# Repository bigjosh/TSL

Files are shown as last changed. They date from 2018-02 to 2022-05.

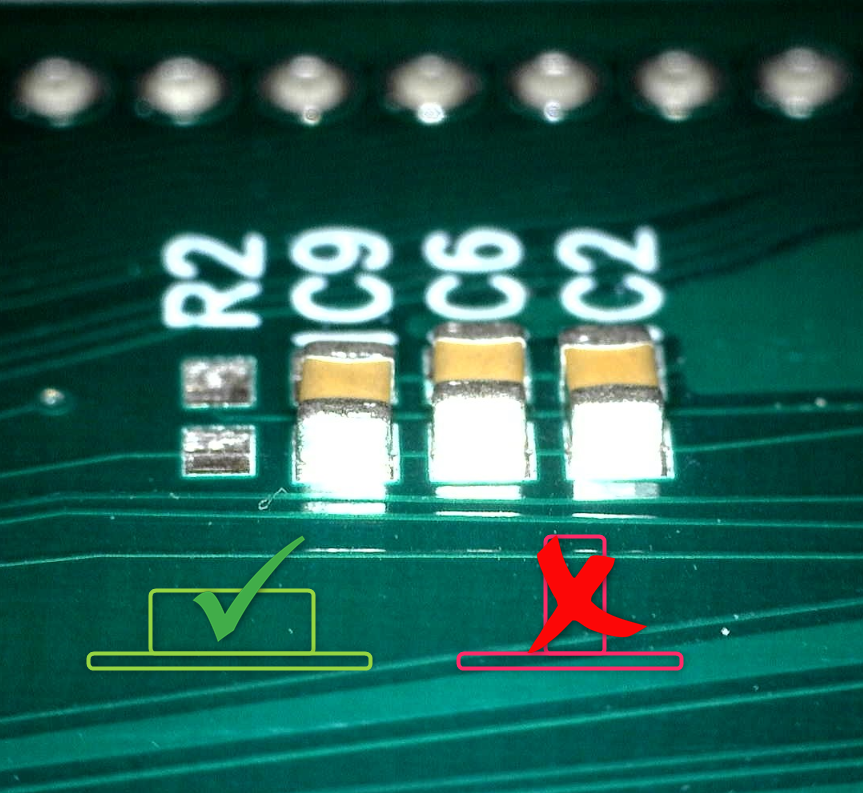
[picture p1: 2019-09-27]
hardware/orientation photos/orientation C2-C6-C9.png

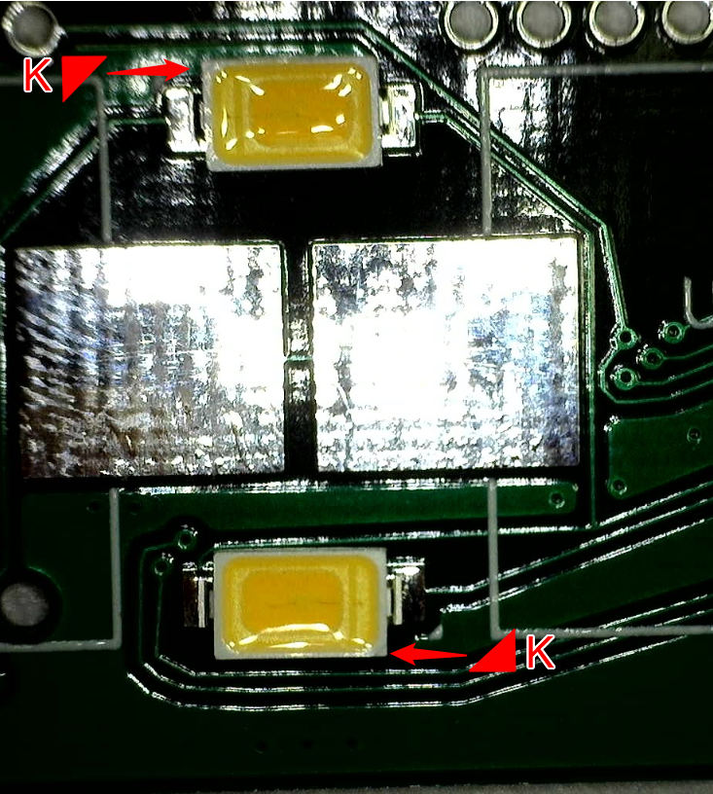
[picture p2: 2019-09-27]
hardware/orientation photos/orientation L1-L2.png

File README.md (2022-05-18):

# TSL



PCB and firmware for the CW&T Time Since Launch project.

Buy one here...
https://shop.cooperhewitt.org/products/time-since-launch

Or here...
https://www.uncommongoods.com/product/time-since-launch-clock

## Design goals:

* Run for decades on 2xAA batteries.
* Stay accurate to to within ±2ppm over the lifetime.  
* Replaceable batteries, with continued timekeeping during a reasonable battery swap time period.  

## Critical parts:

* ATXMEGA128B3 processor for LCD driving and supervision. 
* RX8900 RTC for precision timekeeping
* 2x  AIExpress 6-digit, 7-segment dynamic LCD glass 
* 2x Energizer Ultimate Lithium AA batteries
* Optional 32768Hz tuning fork quartz watch crystal 

## XMEGA EEPROM usage

We use a block at the start of EEPROM to ...

1. Initially set the current real time on first power up at the factory.
2. Remember that we set the current time at the factory. 
3. Remember if/when the trigger was pulled.
4. Remember if the RTC has ever lost power. 
 
Here is the format of that block...

    #define EEPROM_ADDRESS_STARTIME     EEPROM_ADDRESS( 0)  // Set by the at the Factory to real time GMT when initially programmed. RX8900 register block layout. Values are BCD.
    #define EEPROM_ADDRESS_STARTFLAG    EEPROM_ADDRESS( 8)  // Set 0x00 to indicate that STARTTIME block has time in it, set to 0x01 when STARTTIME set to the RTC the first time we power up

    #define EEPROM_ADDRESS_TRIGGERTIME  EEPROM_ADDRESS(10)  // Set to RTC time when the trigger pin is pulled. RX8900 register block layout. Values are BCD.
    #define EEPROM_ADDRESS_TRIGGERFLAG  EEPROM_ADDRESS(18)  // Set to 0x01 when the trigger pin is pulled and the RTC time is aves to the TRIGGER_TIME block.

	#define EEPROM_ADDRESS_LOWVOLTFLAG  EEPROM_ADDRESS(20)  // Set to 0x01 if we ever power up and find a low voltage condition.

The times are in RX8900 register block format....

| Address | Function |
| - | - |
| 00 |  SEC | 
|01  | MIN | 
|02  | HOUR |
|03  | WEEK |
|04  | DAY |
|05  | MONTH | 
|06  | YEAR |
|07  | RAM |

We ignore the `WEEK` register, but set it to a sensical value (1-7) since the datasheet warns of problems otherwise. 

We use the `RAM` location to hold our century interlock. 

### Century interlock

The RX8900 only saves 2 digits for the year, so when we roll from 2099 to 2100, the year will go from 99 to 0.
This would make us loose 100 years worth of days on the first battery change of the new century when we go to
compute how long since the pin was pulled.

To buy ourselves extra centuries, we use a century interlock stored in the RAM register of the RX8900.
When we first program a unit (presumably in the 1st half of the 2000 century), we set the interlock to '00' BCD (0x00).

On every power up (typically due to battery change) every 10 - 30 years(? We'll see!), we check the current year. If it is greater than 50 and the century interlock is even, then we increment the century interlock. If it is less than 50  and the century interlock is odd, then we increment the century interlock. This also has the effect of re-writing the EEPROM every few decades, which [may or may not extend the retention](https://electronics.stackexchange.com/questions/411616/for-maximum-eeprom-readability-into-the-future-is-it-better-to-write-once-and-le). 

When we want to compute the total days elapsed since epoch Jan 1, 2000 then we divide the century interlock by 2 and drop the remainder. We when multiply this by the number of days in an RX8900 century and we will get the correct value.

This will get us an additional 127 centuries of run time, which puts us at the year 14700. We will need to patch the firmware before then if we want to continue to keep accurate count.

### The leap year problem

The RX8900 counts any year ending in `00` as a leap year, but in real life 2100 is not a leap year.

This means that if a unit is programmed in the 2000's and triggered on 3/1/2100 then the trigger date in EEPROM will be 2/29/2100, and any day after that will be 1 day behind the actual calendar date when the trigger was pulled. The count will still always be right, and the only way you'd know about this is if you inspect the trigger time with the diagnostic mode or if you have to reset the RTC.

This divergence will increase by 1 for each non-leap year ending in `00` after 2000, including 2200 and 2300 (2400 is a leap). 

Why don't we just correct for this in the firmware? Well because as far as the RX8900 is concerned 2/29/2100 actually happened, so a trigger could happen on that day.

Since this problem is predicable we can account for it when resetting the RTC in units triggered after 2/28/2100. 

## Method of Operation

### Factory power up
The factory burns the firmware into flash and also stores the current GMT time into `STARTTIME` in the EEPROM block. 

On initial power up, firmware sees a new `STARTTIME` block in EEPROM and uses it to set the RTC. It then sets the `STARTFLAG` so that the time is not programmed again on subsequent power ups and executes a software reset to being normal operation with the new start time.  

If the trigger pin is out at start up we go into clock mode and show the current GMT time until the pin is inserted. THIS CLOCKMODE IS MEANT FOR TESTING ONLY. It is very high power (like 50x normal count!), so be sure to insert the pin as soon as you have verified the correct time. DO NOT USE A TSL IN CLOCKMODE AS A CLOCK. If you really want a TSL clock, we can make you power efficient firmware for that. 

Once the pin is in, we go into Ready To Launch mode. 
 
## Display modes

### Warm up mode

Every time the XMEGA powers up (on initial programming or after battery change), it will display a pretty sinewave pattern for 2 seconds while it waits for the RX8900 RTC to oscillator to stabilize. 

Do we need this? Well we certainly do not need it if the RTC is already running, but it is unclear if we can poll the RTC to see if it is running before the oscillator has settled. The datasheets are unclear. 
> 
> "Please perform initial setting only tSTA (oscillation start time), 
> when the built-in oscillation is stable."
> 

...so we wait. 

### Reset flags mode

For testing only - removed from production firmware.

Displayed for 2 seconds after each reset. Shows the reset flags currently set. We clear the flags after testing them, so there should only be one flag set indicating the reason for the most recent reset. 

Shows the word `rESEt` on the left LCD and the following possible flags on the right LCD...

| Letter | Name | Description |
| - | - | - |
| P | Power On | Initial power up |
| E | External | The RESET pin was pulled low<br>(We disable this pin)  |
| b | Brown out | Brown out voltage reached<br>(We disable the brown out detector) |
| d | Download | PDI download triggered reset |
| S | Software | Software generated reset<br>(We trigger this after setting the time) |
| U | Undefined | One of the two undefined flags were set |  

### Set Clock mode

Shows "SEt CLoC" on the LCD.  

Shown when we initially set the start time from EEPROM into the RTC during factory programming. 

After this we execute a software reset.  

### Clock mode

Shows current real time as MMDDYY HHMMSS with blinking ":"'s.

This time comes from the RTC and should be correct GMT ±2ppm if it was programmed correctly at the factory. 

This mode is shown at start up if we have a good start time, but no trigger time and the pin is not inserted. 

We existing this mode when the pin is inserted and goto Ready To Launch mode.     

WARING: Clock mode uses about 50x as much power as normal Time Since Launch mode, so don't leave it on for too long! For diagnostics only! 

### Ready To Launch mode 

Shows a mesmerizing winding pattern with 1Hz update rate. 

The purpose of this pattern is to show the user that we are ready and willing, and also make apparent any bad LCD segments stuck either on or off. 

We enter this mode on power up if the trigger pin has never been pulled before, and we exit it when the pin is pulled. When the pin is finally pulled, we blink the flashbulb LEDs and save the current time from the RTC into EPPROM in the `TRIGGERTIME` block to remember the trigger time and set the `TRIGGERFLAG`.  

### Time Since Launch Mode

Here we count up the days, hours, minutes, and seconds since the trigger was pulled. 

When we reach 1,000,000 days we switch to Long Now mode. 

### Where Has the Time Gone mode

Shows the time the trigger pin was pulled in MMDDYY HHMMSS blinking at 0.5Hz. 

Indicates that the trigger pin was pulled and we marked the moment shown on the display, but since then the real time was lost (RTC lost power) and needs to be set before we can show Time Since Launch mode. 

The unit can be factory serviced and set with the correct real time and it will pick up where it left off. 

### Clock Error mode

Shows `cLoc Error` blinking forever.

Indicates that the trigger pin has never been pulled, and that the real time was lost. The start time must be set again before we can go to Ready To Launch mode.    

This likely means that the unit was stored as old new stock for 100+ years and the batteries we allowed to go completely dead before first use. The unit can be factory serviced to set the real time and then will be ready for first trigger.   

### Low Battery mode

Blinks the little battery icons at 1Hz to indicate that a low battery voltage was detected.

The battery voltage is checked once at start power up and then every 8 days in Time Since Launch mode starting at the update from day 0 to day 1. If the voltage is less than about 2.6 volts, then we go into low battery mode.

When you see this, you should swap out the batteries for new ones. No need to run, you likely have moths to years to get it done before the time is lost. Be sure to use Energizer Ultra.  

Work quickly, you may have as little as 10 seconds of coast time if the battery voltage is very low. Be sure to have the new ones ready before you remove the old ones. Change the batteries one at a time - taking the first old one out and putting the new one in, then taking the second old one out and putting the new one in. This will minimize the amount of time that the unit is completely unpowered (even having low batteries installed will charge the RTC hold over capacitor). 

If after you change the batteries you still see low battery mode, then pull one of the batteries out and wait for the LCD to go blank and then quickly put the battery back in. 

Note that we intentionally do not check for low batteries during Ready to Launch mode. It is expected that a TSL will spend most of its decades in Time Since Launch mode, so no point in wasting good power right at the beginning of its long life. Also, what cut off would we use? Should it be higher than the cut off during Time Since Launch mode? If your TSL has been sitting around for more than 20 years and you are about to have a big moment and you want to play it safe, you can always prophylacticly put in new batteries. 

### Long Now mode

Shows `999999 235959` blinking forevermore. 

Indicates that the trigger was more than 1 million days (~2740 years) ago so we can not display it accurately. 

The idea here is to avoid problems of people trying to ebay old TSL units that have rolled over by misrepresenting their true age. 

### Bad Interrupt Mode

Shows "bAd Int" blinking forever.

This means that an unexpected interrupt happened. This would be very unexpected indeed.  

The only interrupts that are ever enabled are for the trigger pin and the 2Hz FOUT tick (risgin and falled edge of 1Hz) coming from the RTC, and we turn off the trigger pin after the pin is pulled.

### EEPROM Error Mode

Shows `EEPro ErrorX` blinking forever.

This is shown on start-up if the EEPROM is in an inconsistent state. This usually means either that the EEPROM was never programmed (it defaults to 0xff's), or it got corrupted somehow. 

The `X` after `EEPro` is a code that tells you the first problem found (they are checked in order). 

| Code | Reason 
| - | - |
| 1 | Invalid `LOW VOLTAGE FLAG` |
| 2 | Invalid `START FLAG` |
| 3 | Invalid `TRIGGER FLAG` |
| 4 | `TRIGGER FLAG` set but `START FLAG` not set |
| 5 | `TRIGGER TIME` is in the future | 
| 6 | _[elided]_ |
| 7 | Invalid `START TIME` | 
| 8 | Invalid `TRIGGER TIME` | 

#### Codes 1-3

All flags must have a value of either 0 (not set) or 1 (set).

#### Code 4

How could the user have pulled the trigger if we never set the start time? Impossible. 

#### Code 5

To find the Time Since Launch, we need to subtract the time now from the `TRIGGERTIME`, so the `TRIGGERTIME` must be *before* now. 

#### Code 6

[elided] 

#### Code 7 

`STARTTIME` failed validity checks on start up. (i.e. month was greater than 12)

#### Code 8 

`TRIGGERTIME` failed validity checks on start up. (i.e. month was greater than 12)

## `STARTTIME` delay offset

When programming the `STARTTIME` into the EEPROM, be sure to account for (1) the time it takes to generate the EEPROM file and program it into the unit, and (2) the 1 second warm up delay when the unit first comes up. 

## Diagnostics

### Factory program

On the initial power-up after the time as been set to the value supplied in the `STARTTIME` EEPROM block, the display will show the Clock mode for as long as the trigger pin is out. 

This is handy for verifying the correct time was programmed. 

### Field service 

There are two test pins on the 6-pin ISP connector on the board labeled `B` and `T`. They are internally pulled up, so you connect them the to the ground pin (labeled `G`) to activate them.

The reset pins are checked at start up and at the end of each hour. 

#### `B` Pin

Grounding the `B` pin will show a series of three display phases, switching once per second.

The sequence will repeat if pin `B` is still grounded after phase 3 is displayed.  

##### Phase 1

The LCD displays the `STARTTIME` block from EEPROM. 

Left `:` is on to differentiate this display. 

##### Phase 2

Will show the stored trigger time. The left & right `:`'s are lit to differentiate this display.

The display will show "no triG" if the EEPROM trigger flag is not set.   

The right `:` is lit to differentiate this display.

(Note this changed in ver 1.04)

##### Phase 3

The left LCD module shows `XXVOLt` where `XX` is the current Vcc voltage as read by the XMEGA analog to digital converter. There is an implied decimal point between the two digits, so `31VOLT` means the XMEGA just sampled the Vcc as 3.1 volts. Note that this voltage can be slightly lower than what it will be when running normally because this diagnostics screen uses much more current than the normal modes do.    

The right LCD module shows `VErXXX` where `XXX` is the current firmware version as defined in the TSL.c source code. There is an implied decimal point between the first and second digits so `VER101` indicates firmware version 1.01.    

#### `T` Pin

Grounding the `T` pin will show  current time as loaded from the RTC on the display. This will show even if the clock has not been initialized. 

Left decimal point means low voltage flag set in RX8900 right now.

Right decimal point means low voltage flag is set in EEPROM (we have seen a low voltage on RX8900 in the past). Once set, the low voltage flag in EEPROM stays set forever. 

The low voltage flag indicates that the voltage to the RTC dropped low enough that the RTC at least stopped counting, and possibly lost all the values in the time registers.

The RX8900 low voltage is checked and the EEPROM flag is set *after* this diagnostic screen, so you can see the RTC showing low voltage but the EEPROM flag not set if this is the first time we are powering up since the low voltage event happened on the RTC.  

The low voltage flag is cleared in the RX8900 when it is programmed with the start time at the factory. 

(Note this changed in ver 1.04)

## Interesting twists

We actually have two oscillators running simultaneously here.

The ATMEGA uses either the XTAL or the internal ULP oscillator to drive the LCD controller. The xtal uses about 0.3uA less current, but requires an extra part (the ULP is built in to the XMEGA).  

The RX8900 is programmed to generate a 1Hz output pulse (FOUT) that is connected to an IO pin on the XMEGA. The rising and falling edges of each of these pulses causes an interrupt on the XMEGA which wakes it from deep sleep. On waking, the XMEGA checks the FOUT pin to see if it has changed, and if not then it goes back to sleep. We do this to filter spurious interrupts that can be caused by noise from static electricity from rubbing the glass.  

On the falling FOUT edge the XMEGA then increments the count and updates the display and goes back to deep sleep until the next interrupt. 

The resistor on the FOUT line is to reduce the amount of current that flows from the RTC into the MCU during a battery change. This current can flow because there is an internal clamping diode inside the MCU that is forward biased if the pin voltage is higher than the Vcc voltage, which can happen during a battery change since the RTC is running off of the backup capacitors but there is no power to the MCU. We hope that RTC will stop driving FOUT when it sees FOE drop (FOE is connected to the MCU Vcc line). 

Diode D1 serves two purposes. Firstly, it prevents power from flowing from the backup capacitors into the MCU during a battery change. This will hopefully extend the time the user has to successfully complete the change since the RTC alone uses much less power than the MCU. Both sides of the diode also serve to protect both the MCU and RTC from reverse voltage in the case the batteries are inserted backwards.     

We also did a lot of work to save power on the display updates by basically writing an optimizing compiler that transforms a sequence of LCD steps (like `0000` to `5959`) into minimal cycle count AVR assembly language that will display those steps. Do read more about it in the [code2code.MD document](code2code.md).      

## Build notes

gcc optimization: `-O3 -flto`

```
-x c -funsigned-char -funsigned-bitfields -I"C:\Program Files (x86)\Atmel\Studio\7.0\Packs\atmel\XMEGAB_DFP\1.1.55\include"  -O3 -flto -ffunction-sections -fdata-sections -fpack-struct -fshort-enums -g2 -Wall -mmcu=atxmega128b3 -B "C:\Program Files (x86)\Atmel\Studio\7.0\Packs\atmel\XMEGAB_DFP\1.1.55\gcc\dev\atxmega128b3" -c -std=gnu99 -MD -MP -MF "$(@:%.o=%.d)" -MT"$(@:%.o=%.d)" -MT"$(@:%.o=%.o)" 
```

## Fuse programming notes

The only change we make to default fuses is to change `FuseByte4` to `0xEE`.

This sets the `RSTDISBL` fuse...

> Bit: 4 – RSTDISBL: External Reset Disable
> This fuse can be programmed to disable the external reset pin functionality. When this is done, pulling the r
> ill not cause an external reset. A reset is required before this bit will be read correctly after it is changed

We do this to avoid inadvertent resets. We have seen cases where the built-in pull-up on the reset line is not enough to resist a strong electric field generated by static electricity on the outside of the tube in dry winter conditions. 

## Unit factory programing

Check out the [programming readme](programming/readmne.MD) for more info. 

## Current Usage

| Mode | Vcc=3.55V| Vcc=2.6V |
| - | -: | -: |
| Ready to Launch | 5.5uA | 5.3uA | 
| Time Since Launch | 6.0uA | 5.4uA |
| Long Now | 4.7uA | 4.2uA | 
| Low Battery | 3.9uA |  3.5uA |
| quiescent | 3.9uA | 3.4uA |

Quiescent mode means that all LCD segments are turned off, interrupts are disabled, and the XMEGA is put into Power Save mode. The only current draw should be from the RX8900 and the XMEGA quiescent power.   

3.55V is approximately the voltage of a pair of fresh Energizer Ultra batteries.
2.6V is approximately the voltage when we drop to Low Battery mode.

Note that voltage drop over time is not expected to be linear with Energizer Ultra cells. These batteries are predicted to spend most of their lives towards the higher end of the voltage range and only start dropping when they get near to their end of life.  

### Color

Comparing Time Since Launch mode to Long Now mode lets us see how much power is used in the the timekeeping code.  

Comparing Low Battery mode to Long Now mode lets us see how much of the power is dependent on just how many LCD segments are lit.

Comparing maximum and minimum operating voltages for different modes lets us see how much of the power usage is dependent on supply voltage, and how that relates to time spent in sleep versus active mode (Time Since Launch spend a lot of time in active, whereas Long Now and Low Battery spend almost none).

Comparing Low Battery mode to quiescent mode lets us see how much power used by the interrupt ISRs (confounded slightly by those tiny little battery icon segments and the single blink instructions in Low Battery mode).    

### Conclusions

There is not much to be gained by elimination the ISR overhead. This is surprising. Those unnecessary PUSHes and POPs still bug the crap out of me. 

There are gains of up to 1uA possible from having fewer LCD segments lit. Not sure how actionable this is. We could, say, save 0.5uA by blinking the Time Since Launch mode screen off every other second. It is likely that Ready To Launch mode's low power relative to Time Since Launch mode is due to the fact that it has only 1 segment lit per digit. 

Probably the best place to focus effort is on the Time Since Launch update code since there is about 1uA on the table and the device spends the vast majority of its live here.  

### Measurement conditions

Production board from initial batch. Bare PCB on my desk (not in tube).  
68F
80%RH

(Higher humidity and temperature tends to increase current consumption. Need some different weather conditions to quantify this!) 

## Status

Firmware is Feature complete but could use more testing. 

We are at an average of <6uA running current over the full voltage range.

If the battery datasheets are to be believed, this suggests a runtime of ~66 years. Even derating a few percent for internal leakage, we should get a decent run time between battery changes. 

## Future directions

### Software 
Find a way to suppress the ISR call on interrupts. Maybe by playing with interrupt priorities? We do not use the ISR and just do an empty return, so why waste all those cycle on PUSHing and POPing. 

### Hardware

Trivially reroute J2:2 and J2:3 to avoid the unnecessary vias. I know one will ever see these because they are under the LCD and battery holder, but still they bug me.    

Add a supplemental pull-up resistor to ~RESET line. In dry conditions it is possible to reset the XMEGA over the built-in pull-up when it is in the tube using static fields. Don't really need this since the firmware is spurious RESET tolerant, but cleaner.

Try using the ~INT line from the RTC to trigger an update on the MCU. We would use an internal pullup on the MUC pin. Since this pin on the RTC is open collector, this would eliminate any power drain from the RTC to the MCU during battery changes. To be seen if this set up uses significantly more power during normal operation since the RTC is shorting the pull-up to ground. We could potentially turn off the pull-up very quickly after waking, and then wait to turn it back on until we know that the ~INT pin is open again. The ~INT pin is closed fort about 7ms and then automatically opened again, so we could probably use the Watchdog timer to sleep during this period.

Add an Ultra-Low Quiescent Current Low-Dropout Linear Regulator in front of the XMEGA. The current drops from 5.6uA@3.2V to 4.2uA@2.0V, so some potential for savings here, but worth the extra part?  

Try driving the LCD bias voltages directly from the battery voltage. The Energizer Ultra's have remarkably stable voltage over most of their lives and we go into Low Battery mode when they start to drop, so might be able to save power by disabling the XMEGA charge pump and finding contrast settings that work with the battery voltage direct?

If possible find a static LCD and bit bang the segments. Since our batteries have such a flat voltage curve, we could avoid the biasing circuits and charge pump and save a lot of power.  

If the datasheets are to be believed, switching to an ultra low power ARM (like SAM22L or STM32L) or STM8 could reduce power drastically, at the cost of higher cost. This needs to be tested.

It might be possible to do temperature compensation inside the MCU and get rid of the RX8900 while achieving more accuracy (would take a higher precision temp sensor than the one in the RX, and better characterization of each individual unit) . While this could also potentially save power in theory, it seems unlikely that it would in practice since that part astonishingly pulls less than 1uA in practice.

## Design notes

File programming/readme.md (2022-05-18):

# TSL Factory Programming

Each TSL needs to get programmed with firmware and the current time before it can launch!

This setup assumes you are programming using a Windows computer with Atmel Studio 7 installed and an Atmel MkII programmer.

TODO: This windows stuff is hokey and brittle. Use a dedicated Raspberry Pi with GPS to do programming.

## Set up

Get to a command prompt in the directory with this readme. 

Make sure your computer has the right time and date. It is probably a good idea to install an NTP client or GPS slave at some point to keep the time accurate to the second.

### Adjust `atprogram` path 

Find the location of you "atprogram.exe" that was installed with Atmel Studio. If it is not at `C:\Program Files (x86)\Atmel\Studio\7.0\atbackend\atprogram.exe` then edit the `burnthis.bat` file to fix the path.

### Adjust programming lag offset

Since all time calculations inside a running TSL are relative, it does not practically matter how accurate the programmed clock time is for normal operation. Having accurate TSL time is nice when a TSL needs to be reset. It is also nice to have it accurate to +/-1 second just so we can keep track of how how much TSLs are drifting in the wild over time.     

The programming procedure takes more than a second to complete, so if we just programmed the current time then the TSL would end up behind.

You can specify a number of seconds to add or subtract to the current time when programming the TSL to account for these delays in the programming process. 

First try programming a unit with the default offset and then compare the clock time on the TSL to the the time on the computer. If the TSL is off by more than +/- 1 second then adjust the value of `offset` in the `burnthis.bat` file and try again.

### Accurate time base

We want the local windows clock to be as accurate as possible since all the TSLs programmed will be based on this time (+/- the lag offset above). You can manually set the windows clock though Windows' settings, but probably best to install an NTP client on the programming computer to always keep it synced.

Here is one that is free and works...

http://www.timesynctool.com/

You can check against the real time here...

https://time.gov/

## Procedure

1. Connect the TSL to the programming jig.
2. Enter the command `burnthis.bat` on the command line followed by the unit serial number. (Use up arrow or F3 on subsequent passes)
3. Watch it program.
4. Remove the TSL and check that is has the correct GMT time on the LCD.
5. Insert the trigger pin.
6. Confirm that the TSL goes to Ready To Launch mode and all the segments look good.

### Batch programming mode

If you enter just `burnthis.bat` without specifying a serial number, then you will go into batch programming mode where You will be asked to enter a serial number and after the programming cycle successfully competes then it will ask for the next serial number. 

This works great if you have a bar code scanner to enter the serial numbers.   

## How it works

### tsl-make-block

First the batch file uses the `tsl-make-block` to create a binary file to be programmed into the TSL EEPROM. The program checks the clock on the local PC, converts the current time to GMT, and then adds in the delay offset. Then it writes out the EEPROM data block in the format that the TSL firmware expects to find when it runs. The block contains:

1. The current time GMT
2. A flag that tells the firmware to copy this time to the RX8900 RTC when it sees it
3. The trigger time and flag, which we set to "not triggered yet". 
4. A flag that remembers if the RTC in the TSL has ever reported that it lost power, which we initialize to `not set`.
 
### atprogram
The batch file uses the `atprogram` command to actually download the firmware flash image and the newly created EEPROM data block into the XMEGA on the TSL.  The `atprogram` is equivalent to `avrdude` but it written by Atmel and runs on Windows and uses the Atmel drivers. We used `atprogram`  because `avrdude` can have problems talking to an `MkII` when Atmel Studio is installed because of USB driver conflicts.  

#### Fuses

The `atrprogram` command sets the fuses like so...

JTAGUSERID = 0xFF
WDWP = <none selected>
WDP = <none selected>
BOOTRST = APPLICATION
TOSCSEL = XTAL
BODPD = DISABLED
RSTDISBL = [X]
SUT = 0MS
WDLOCK = [ ]
JTAGEN = [X]
BODACT = DISABLED
EESAVE = [X]
BODLVL = 1V6

FUSEBYTE0 = 0xFF (valid)
FUSEBYTE1 = 0xFF (valid)
FUSEBYTE2 = 0xFF (valid)
FUSEBYTE4 = 0xEE (valid)
FUSEBYTE5 = 0xF7 (valid)

### Airtable integration

The programming cycle automatically inserts a record into the [Units database](https://airtable.com/tblunHqmlHFKtvaZ1/viw4lIvKlyMFLtk5F) for each unit programmed. 

Before creating the record, it checks so make sure there is already a record for the current firmware hash in the [Firmwares database](https://airtable.com/tbl5LY3zBKoeetbQW/viwRVB4nIbvjLaZ3i). If not, then it will fail with an error. If this happens, you need to add a record for the new firmware version.

### Airtable API key 

In order to update the databases in Airtable.com, this batch file needs to know your Airtable API key. You can get it here...

https://airtable.com/account

Copy the value if one is there, hit generate if not.

The first time you run the procedure below, you will be prompted to enter the API key. The key you enter will be stored in the Windows registry for the local user on the local computer so you do not need to enter again.

If you ever want to remove the stored API key (you are selling the computer, or you need to enter a new value), you can run this command...

`REG delete HKCU\Environment /V burnthis_airtable_api_key`

...and the next time you run `burnthis.bat`you will be asked to enter a new key.

### Checking your work

You can use the `read-eeprom.bat` batch file to read and print the eeprom of an attached TSL. It uses the `tsl-read-block.exe` utility to decode and print the data, and you can also use this utility to work directly with eeprom bin files created by `atprogram.exe` or the `Device Programming` function under `Tools` in Atmel Studio.  

### Sample block file

The `party-like.bin` eeprom block will set the clock to just after midnight on Jan 1, 2000. You can use the Atmel Studio "Device programming tools" or AVRDude to load this file into EEPROM for testing.

It was created with this command line...
```
tsl-make-block.exe party-like.bin -s 20000101000000
```

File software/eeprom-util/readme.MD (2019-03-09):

These utilities let you create and print TSL eeprom binary images. 

While you can use them direct on files, you usually want to use the batch files in `/programming` to access them.

Note that if you change any of these programs, you should copy the new binary to `/programming/eeprom-utils/bin`.

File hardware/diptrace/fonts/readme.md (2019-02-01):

The text on the bottom of he board uses the `Space Mono` font included here.

It must be installed on the computer to be able to generate gerber files for this PCB.

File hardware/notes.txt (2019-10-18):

1.
No ultrasound cleaning - RTC clock part U3 is sensitive to vibration.

2.
LCD parts L1 and L2 are to be hand soldered. They mount with the LCD face on the FRONT side of the PCB. 

3.
LCD parts L1 and L2 are heat sensitive. Avoid overheating when soldering.

4.
Use the solder reflow profile for RTC clock part U3, available on page 42 here...
https://support.epson.biz/td/api/doc_check.php?dl=app_RX8804CE&lang=en
Following this profile is critical for the performance of this part. 
All other parts are tolerant of this profile.

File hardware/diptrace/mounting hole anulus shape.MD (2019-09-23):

How to make an anulus from...
https://www.diptrace.com/forum/viewtopic.php?f=2&t=10961

---
Maybe someone else knows of a simpler method, but I haven't figured one out yet. Until then, here is a very involved procedure for getting the pad you need...

Phase I - Option A: Using DipTrace drawing tools
1) In the PCB Layout editor, clear the design area of all objects and make sure Units is set to mm.
2) Using the 2D drawing tools, create the desired shapes (in this case, two circles) in the Top Assy layer centered about the origin (0,0).
3) Go to the Main Menu and click on File, then Export and then DXF...
4) In the Export DXF dialog window, select the Top Assy layer, set Units to mm and enable the option [x]Use Design Origin.
5) Click on the [Export] button and save as a file named sketch to a convenient location (e.g. Desktop).

Phase I - Option B: Using a separate 2D Cad drawing program
1) Create the desired shapes (in this case, two circles) centered about the origin (0,0) using millimeters as your units.
2) Save as a *.DXF file named sketch to a convenient location (e.g. Desktop).

Phase II
1) In the PCB Layout editor, clear the design area of all objects and make sure Units is set to mm.
2) Go to the Main Menu and click on File, then Import and then DXF...
3) Select the newly-created file named sketch.dxf.
4) In the Import DXF dialog window, set DXF Units: Millimeters, Import Mode: Add, Convert Blocks: None, Convert to: Top, enable options [x]Fill closed areas and [x]Embedded Polygons.
5) Click on the [Import] button.
6) Go to the Main Menu and click on File, then Export and then DXF...
7) In the Export DXF dialog window, select the Top layer, set Units to mm and enable the option [x]Use Design Origin.
8) Click on the [Export] button and save as a file named pad to a convenient location (e.g. Desktop).

Phase III
1) In the Pattern Editor, create a new pattern name and clear the design area of all objects. Make sure Units is set to mm.
2) Go to the Main Menu and click on Pattern and then Import from DXF...
3) Choose the newly-created file named pad.dxf.
4) In the Import DXF dialog window, set DXF Units: Millimeters, Import Mode: Add, Convert to: Top Pads, enable options [x]Fill Closed Areas and [x]Embedded Polygons.
5) Click on the [Import] button.

Note: Due to how this special pad was created, you will not be able to resize it. Also, copying this special pad will result in the copies having the same pad number. You will have to manually renumber those additional pads.

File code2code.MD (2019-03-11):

# LCD update code that writes code

To save power, we want to spend as much time sleeping as possible. When we wake up, we need to update the LCD display as quickly as possible and then go back to sleep.

To this end, we want to find the optimal set of instructions to update the LCD display from the current value to the next one in as few cycles as possible. We need an LCD compiler!

The LCD display segments are represented as bits in the XMEGA LCD registers. Because the LCD module is multiplexed, these bits are not contiguous across registers. The bits for the segments in each digit are spread across as many as 4 registers (one for each of the common pins). 

Luckily the registers ended up organized so that each group of 4 registers controls a contiguous block of four digits. Here is a map of which registers hold segments for each of the 12 digits...  

### LCD register usage by digit map

| Reg  | 11 | 10 | 09 | 08 | 07 | 06 | 05 | 04 | 03 | 02 | 01 | 00 |
| ---  | -- | -- | -- | -- | -- | -- | -- | -- | -- | -- | -- | -- |
| [00] |  X |  X |  X |  X | | | | | | | | |
| [01] | | | | |  X |  X |  X |  X | | | | |
| [02] | | | | | | | | |  X |  X |  X |  X |
| [03] | | | | | | | | | | | | |
| [04] |  X |  X |  X |  X | | | | | | | | |
| [05] | | | | |  X |  X |  X |  X | | | | |
| [06] | | | | | | | | |  X |  X |  X |  X |
| [07] | | | | | | | | | | | | |
| [08] |  X |  X |  X |  X | | | | | | | | |
| [09] | | | | |  X |  X |  X |  X | | | | |
| [10] | | | | | | | | |  X |  X |  X |  X |
| [11] | | | | | | | | | | | | |
| [12] |  X |  X |  X |  X | | | | | | | | |
| [13] | | | | |  X |  X |  X |  X | | | | |
| [14] | | | | | | | | |  X |  X |  X |  X |
| [15] | | | | | | | | | | | | |
| [16] | | | | | | | | | | | | |

Notice how digits 00-03 all use the same set of registers (02, 06, 10, and 14)?

This means that as long as we know the full current value for the first 4 digits, we can blindly write to these registers without having to load them, adjust the bits, and rewrite them.

With all this in mind, we now know that we can represent an hour of updates (0000-5959 in the rightmost 4 digits) with a sequence of blind writes to registers 02 ,06, 10, and 14! 

This is a total of 3600 updates to these registers, but the updates are not just increments or bit shifts because the bits represent the 7 physical visible segments on the LCDs. For example, to show a `0` we have to light 6 segments, but to show a `1` we only have to light 2 segments. See?

So we have to map the LCD font into the bits of the registers. The fastest way to do this is to precompute the needed values for each of the 4 registers for each of the 3600 steps. 

We could store all of these precomputed values in an array in flash and then load them in a loop, but loading data  from flash costs cycles as does the overhead of loops. Since we have plenty of flash memory available, we instead will just explicitly hardcode each step into the sequence of instructions. The pseudocode looks like...

    1. Update register 02 with value that reflects LCD display of 0000.
    2. Update register 06 with value that reflects LCD display of 0000.
    3. Update register 10 with value that reflects LCD display of 0000.
    4. Update register 14 with value that reflects LCD display of 0000.
    5. Sleep until next update
    6. Update register 02 with value that reflects LCD display of 0001.
    7. Update register 06 with value that reflects LCD display of 0001.
    8. Update register 10 with value that reflects LCD display of 0001.
    9. Update register 14 with value that reflects LCD display of 0001.
    10. Sleep until next update
    11. Update register 02 with value that reflects LCD display of 0002.
    12. Update register 06 with value that reflects LCD display of 0002.
    13. Update register 10 with value that reflects LCD display of 0002.
    14. Update register 14 with value that reflects LCD display of 0002.
    15. Sleep until next update
    etc...
    
At first you might say "Why not only update the single register for the digit that changed?" But remember that the bits for each digit are scattered across the 4 registers. 
  
Here is a map of how that happens to land....
         
## Segment map of each digit 

        D
    C       E
        G
    B       F
        A

(NOTE: LCD modules are mounted upside down for maximum contrast when viewed from 30 deg above)
    
## Map of segments to (register:bit)

| Digit | A | B | C | D | E | F |
| - | - | - | - | - | - | - |
| 11 |  00:0 | 04:0 | 08:0 | 12:1 | 08:1 | 00:1 | 04:1 |
| 10 |  00:2 | 04:2 | 08:2 | 12:3 | 08:3 | 00:3 | 04:3 |
| 09 |  00:4 | 04:4 | 08:4 | 12:5 | 08:5 | 00:5 | 04:5 |
| 08 |  00:6 | 04:6 | 08:6 | 12:7 | 08:7 | 00:7 | 04:7 |
| 07 |  01:0 | 05:0 | 09:0 | 13:1 | 09:1 | 01:1 | 05:1 |
| 06 |  01:2 | 05:2 | 09:2 | 13:3 | 09:3 | 01:3 | 05:3 |
| 05 |  01:4 | 05:4 | 09:4 | 13:5 | 09:5 | 01:5 | 05:5 |
| 04 |  01:6 | 05:6 | 09:6 | 13:7 | 09:7 | 01:7 | 05:7 |
| 03 |  02:0 | 06:0 | 10:0 | 14:1 | 10:1 | 02:1 | 06:1 |
| 02 |  02:2 | 06:2 | 10:2 | 14:3 | 10:3 | 02:3 | 06:3 |
| 01 |  02:4 | 06:4 | 10:4 | 14:5 | 10:5 | 02:5 | 06:5 |
| 00 |  02:6 | 06:6 | 10:6 | 14:7 | 10:7 | 02:7 | 06:7 |

## Skipping redundant updates

We can, however, skip updating a register if it happens that none of the bits in that register changed between steps. This happens quite frequently, but it is not obvious when it will happen unless you memorize which segments map to which registers. It is just luck when the next digit happens to not change any segments in a given register. Here is a map of the changes to segments when the digit is incremented...   

## LCD changes by digit (`X`=changed)

| Digit |  COM0 | COM1 | COM2 | COM3 |
| - | - | - | - | - |
 | 00 | X | X | X | X |
 | 01 | X | X | X | X |
 | 02 | X | X |   | X |
 | 03 | X | X |   |   |
 | 04 | X |   | X | X |
 | 05 | X |   | X | X |
 | 06 |   | X |   |   |
 | 07 | X | X | X |   |
 | 08 | X | X | X |   |
 | 09 |   | X |   |   |
 | 00 |   | X |   |   |
 | 01 | X | X | X | X |
 | 02 | X | X |   | X |

So it turns out that we can condense the pseudo code above to...

    1. Update register 02 with value that reflects LCD display of 0000.
    2. Update register 06 with value that reflects LCD display of 0000.
    3. Update register 10 with value that reflects LCD display of 0000.
    4. Update register 14 with value that reflects LCD display of 0000.
    5. Sleep until next update
    6. Update register 02 with value that reflects LCD display of 0001.
    7. Update register 06 with value that reflects LCD display of 0001.
    8. Update register 10 with value that reflects LCD display of 0001.
    9. Update register 14 with value that reflects LCD display of 0001.
    10. Sleep until next update
    11. Update register 02 with value that reflects LCD display of 0002.
    12. Update register 06 with value that reflects LCD display of 0002.
    13. Update register 14 with value that reflects LCD display of 0002.
    14. Sleep until next update
    etc...
    
See how we removed the line...

    13. Update register 10 with value that reflects LCD display of 0002.

..because no bits in register 10 happened to change when updating from `0001` to `0002`?

### Startup

Note that we always want to to all 4 registers when executing step `0000` just so we do not have to worry about what happened to be on the display when we first start.

# Code that makes code

Calculating the correct values of each of the 4 registers for each of the 3600 steps - and then deleting the redundant ones - would be a lot of fiddling and typing.

So instead we will use some code.... to write our code. This is much simpler than it sounds. We will just write a very simple C++ program that does the computations above and uses normal `printf()`s to print out the lines of code that do the updates. We can then run our program, capture its output, and then paste this output into the program that will run on the TSL.

Note that this program does not run on the TSL itself, it runs on a real computer with `printf()`. You have to capture this output (which is source code text) and then manually copy this new source code back into the TSL project. 

This code lives in `software/code2code`. It is currently set up as a Visual Studio project, but you can just as easily compile and run the single `code2code.cpp` source file with GCC. 

## Cutting and pasting

This code that writes code needs to know all about the LCD layout and the register locations and such. I could have made  a fancy system to share all this info between the TSL project and the code2code project and had make files automatically keep them up to date, but since you only have to update `code2code` when some hardware parameter changes in the TSL project (and because I am lazy),  instead now you have to do it manually. Here are the steps...

1. Update the `LCD.c` source with new values.
2. Cut and paste the code between the `cut here` marks from `LCD.c` to `code2code.cpp`.
3. Compile and run the new `code2code` code and capture the output into `output.c`.
4. Copy/paste this new `output.c` to the TSL project, covering over the  one.
5. Rebuild the `TSL` project.
 
# The actual code

So what is the best way to actually implement the pseduo code above on our XMEGA?

## Naive

The simplest method is to update each of the 4 LCD registers with their desired values on each step. 

Each register update requires an `LDI` load (1 cycle) to put the value we want into an XMEGA register, and then an `STS` store (2 cycles) to the LCD register address.      

This gives us 3 cycles per LCD register*  4 LCD registers per update = 12 cycles per update.

12 cycles per update * 3600 updates = 43,200 cycles per sequence

Here is an example update where all 4 LCD registers are updated....

    // ---- Step 3599 (59:59)
    LDI r18,0xff             ; Was UNKNOWN
    STS 0x0D12,r18           ; direct store to LCD register 02
    LDI r18,0xaa             ; Was UNKNOWN
    STS 0x0D16,r18           ; direct store to LCD register 06
    LDI r18,0xdd             ; Was UNKNOWN
    STS 0x0D1A,r18           ; direct store to LCD register 10
    LDI r18,0xaa             ; Was UNKNOWN
    STS 0x0D1E,r18           ; direct store to LCD register 14
    // --- Cycles in this step: 12

## Skip redundant stores

If an LCD register already has a value then we do not need to store that value again on the next step. This does not happen as often as you might hope because the pixels in the digits are spread across the LCD registers, but it does happen when there are two consecutive steps that only have a single pixel change like xxx5->xxx6 or xxx8->xxx9.

Here is an example here only a single register needs to be updated between 59:58 and 59:59 because there is only pixel that needs to change (see which?)...

    // ---- Step 3598 (59:58)
    LDI r18,0xff             ; Was bf
    STS 0x0D12,r18           ; direct store to LCD register 02
    LDI r18,0xea             ; Was 2a
    STS 0x0D16,r18           ; direct store to LCD register 06
    LDI r18,0xdd             ; Was 9d
    STS 0x0D1A,r18           ; direct store to LCD register 10
    // --- Cycles in this step: 9
    SLEEP                    ; Wait for interrupt from TX8900

    // ---- Step 3599 (59:59)
    LDI r18,0xaa             ; Was ea
    STS 0x0D16,r18           ; direct store to LCD register 06
    // --- Cycles in this step: 3

## Indirect stores save a cycle

Indirect stores on the XMEGA with `ST` only take 1 cycle, but there are only a total of 3 indirect pointers (X,Y,Z). We need 4 LCD registers to generally update any digit (or set of 4 contiguous digits). So we pick the 3 LCD registers that are updated most often and we initialize the 3 indirect pointers to point to those. For the 4th (least used) register, we bite the bullet and do an `STS` directly to the address which costs 2 cycles.

The LCD registers are listed in order of popularity in a comment at the top of the output.c file for reference. Here are the current values...

    // Most accessed LCD registers:
    //    REG:  6 Count: 2880
    //    REG:  2 Count: 2868
    //    REG: 10 Count: 2040
    //    REG: 14 Count: 1709
    
The index registers are loaded with the addresses of the top 3 LCD registers at the very top of the `emit_code_for_lcd_steps()` function. Note that we must `PUSH` register `Y` and then pop it again before returning since it is guaranteed to be [saved across function calls](https://www.microchip.com/webdoc/AVRLibcReferenceManual/FAQ_1faq_reg_usage.html).  Luckily these pushes and pops only cost 1 cycle each, so a total of 4 cycles to save about 2040 cycles over the course of the 3600 updates.

Note that X, Y, and Z registers are actually pairs of XMEGA registers r27:r26, r29:r28 and r31:r30. Some instructions use the letters (`ST X`) and others use the numbers (`LDI R27`).  

Here is an example where it only takes 2 cycles to update from 59:58 to 59:59 because only one LCD register changes, and that LCD register is assigned to the `X` index register so it only takes 1 cycle to write to it..

    // ---- Step 3599 (59:59)
    LDI r18,0xaa             ; Was ea
    ST X,r18                 ; 2874 accesses to R06
    // --- Cycles in this step: 2

## Stashing the values that get stored into the LCD registers

Both the indirect `ST` and the direct `STS` store instructions store a value that is already loaded into one of the XMEGA registers. 

The fastest way to load a precomputed value into an XMEGA register is using the `LDI` instruction, which takes 1 cycle. 

Since we have some extra XMEGA registers to work with, we can preload the most used values into specific XMEGA registers and then store from those.

To do this, we sort the values in order of most used and pre-load the most used ones into XMEGA general purpose registers so we can even skip the `LDI` sometimes and directly store the general purpose register int the LCD register. In the best case where we are updating one of the top 3 LCD registers with one of the cached values and we only need to update 1 of the LCD registers, we can get away with just 1 indirect store of 1 cycle for a digit increment!

Here are the current top LCD register load values   

```
// Most common values saved to LCD registers:
//    Value: 170 Count: 511
//    Value:  42 Count: 328
//    Value: 255 Count: 267
//    Value: 238 Count: 261
//    Value: 234 Count: 240
//    Value: 254 Count: 239
//    Value: 239 Count: 227
//    Value: 138 Count: 216
//    Value: 191 Count: 200
//    Value: 174 Count: 198
//    Value: 168 Count: 190
```

There is some very complicated code to map the values into AVR cache registers since not all registers are the same. We can only sue some register because some are used for other things, some of the registers must be saved before we use them and then restored before we return to the normal C program ("call saved registers"), and some registers can not be a target of the `LDI` instruction so we need to account for the extra cost of loading the value into a temp register and then loading into the target register.

Also note that we need to save a "working register" that is not used as a cache. We use this register to load on the fly any values that did not make it into a cache register.  We pick register r18 for this because we need a register that can take direct `LDI`s.

But is it all worth it! Look at this single cycle update from 59:58 to 59:59...

## Suppressing working register reloads

OK, we are really scraping the bottom of the cycle barrel here, folks!

It is possible that two consecutive loads of the working register could happened to have the save value, in which case we can skip the redundant load.

This is a pretty esoteric case. We would need the same uncached value to get consecutively loaded into different LCD registers (if it was in the same register then it would already get skipped as a redundant LCD reg update above). 

Does it ever happen?....

Wholey crap! Wow! It actually happens 24 times!!! Are you surprised? 

The first time is at 11:11... 

    STEP_0671:               ; 11:11
    // Found value 170 in cache register
    ST Y,r19                 ; 2868 accesses to R02
    LDI r18,0x00             ; Load uncached value into working register
    ST X,r18                 ; 2880 accesses to R06
    // Found value 170 in cache register
    ST Z,r19                 ; 2040 accesses to R10
    // Skipped redundant load of value   0 into working register. Wow.
    STS 0x0D1E,r18           ; direct store to LCD register 14
    // --- Cycles in this step: 6

Then again at 11:13 (the 128 was loaded into r18 at 11:12)...

    STEP_0673:               ; 11:13
    // Found value 234 in cache register
    ST Y,r23                 ; 2868 accesses to R02
    // Skipped redundant load of value 128 into working register. Wow.
    ST X,r18                 ; 2880 accesses to R06
    // --- Cycles in this step: 2

Here are all the occurrences...

    // Value   0 already in working register at step  671 at 11:11. Wow.
    // Value 128 already in working register at step  673 at 11:13. Wow.
    // Value  32 already in working register at step  691 at 11:31. Wow.
    // Value 160 already in working register at step  693 at 11:33. Wow.
    // Value 160 already in working register at step  713 at 11:53. Wow.
    // Value   8 already in working register at step  791 at 13:11. Wow.
    // Value 232 already in working register at step  818 at 13:38. Wow.
    // Value 232 already in working register at step  828 at 13:48. Wow.
    // Value 232 already in working register at step  878 at 14:38. Wow.
    // Value 232 already in working register at step  888 at 14:48. Wow.
    // Value   8 already in working register at step 1151 at 19:11. Wow.
    // Value 232 already in working register at step 1178 at 19:38. Wow.
    // Value 232 already in working register at step 1188 at 19:48. Wow.
    // Value   2 already in working register at step 1871 at 31:11. Wow.
    // Value 130 already in working register at step 1873 at 31:13. Wow.
    // Value  34 already in working register at step 1891 at 31:31. Wow.
    // Value 202 already in working register at step 1998 at 33:18. Wow.
    // Value 106 already in working register at step 2020 at 33:40. Wow.
    // Value 202 already in working register at step 2058 at 34:18. Wow.
    // Value 202 already in working register at step 2358 at 39:18. Wow.
    // Value 202 already in working register at step 2598 at 43:18. Wow.
    // Value 202 already in working register at step 2658 at 44:18. Wow.
    // Value 202 already in working register at step 2958 at 49:18. Wow.
    // Value 130 already in working register at step 3073 at 51:13. Wow.

 OK, this last optimization saved us 24 cycles at 8Mhz over a 1 hour sequence. That adds up to a power savings of less than [one ten millionth of a percent](https://www.google.com/search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). We can expect a TSL with this optimization to get an additional [26.29 seconds](https://www.google.com/search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) of battery life over a 1,000 year run time. I think it is time to go to bed! :)

## Top O the hour

Every time the the hour rolls, this code returns to the main TSL code, which updates the hours and days and does some other rare stuff like maybe checking for low battery. Then the TSL code jump right back into the optimized sequencer to start at 0000 again.

The sequencer code explicitly sets every LCD register on the first step. This simplifies everything and makes it so that (1) you don't have to know what the LCD looks like when you jump into the optimized code and (2) you can make the optimized code loop back and repeat the steps without having to precompute how the final step will leave the LCD. Ultimately this is worth the dozen or so instructions it costs each time the sequence is run. 

## Jump right in

When the TSL starts after a battery change then we starts at whatever time the TSL should be showing (calculated from the internal clock - the trigger time).

We need to make a way that we can start at any step in this 1 hour sequence so we can start at whatever time we need after a battery change. 

To do this, you might think we could just jump to whatever the current time is... but remember that every update in this sequence has an unpredictable number of instructions in it so how do we find the address of the one we want?

Well, I made an amazingly cool jump table system that would set up all the registers and then jump directly into the requested step by push the target onto the stack and then doing a (fake) return.... but it turns out we do not have enough FLASH for all that code!

If you want to be impressed, check out the `/setup-step` [branch](https://github.com/bigjosh/TSL/blob/setup-step/software/cod2code/VS19/ConsoleApplication1/code2code.cpp#L1460).

I the meantime we have no choice but to go ghetto and run though the remaining time in the current hour anytime we wake after a battery change. Once we are back at the top of an hour, we can jump into the optimized code. This is aesthetically displeasing but it is gonna be ok because this code will likely never run in our lifetime, and even then will will run for less than an hour every century. 

...but do go look at the jump table code, I worked really hard on it and it is super smooth. 

## We built it, now let's leverage it!

Ok, we did all this work to basically build an optimizing compiler for LCD updating, and then we run out our time updating code though it.

But what about life before the pin pulls?

It turns out we can run our Ready Mode figure 8 animation though the same optimizer and get all the benefits!

One wrinkle is that the ready mode repeats indefinitely until the trigger pin is pulled, rather than a fixed number of steps like the hour steps.

To handle this we add two new parameters to the code emitter: the interstep macro and a loop flag. 

The interstep macro is inserted between each step of the sequence. For the hour display, it just sleeps and then interlocks on FOUT to make sure 1 second has passed. For the ready display, it also checks the trigger pin and if the pin is pulled then it immediately returns. Things are set up so that on that return all of the register and the stack are restored before returning to the caller of the optimized function. 

## Heck, mind as well make a sine wave display

If you have a compiler, use it! I made a new sine wave display that looks real nice. Here I made the interstep macro check the LCD frame complete flag, so the display updates as fast as the LCD can show the next fame. Sweet! 

We can use this to replace the boring dashes display at startup!

## Results

### Cycles 

| Optimization | Total Display Update Cycles |
| - | -: |
| None | 43,200 |
| Skip redundant stores |  28,377 |
| Use 3 index registers |  20,595 |
| Use cache registers |  15,845 |
| Suppress redundant working register loads | 15,821 |

### Power 

Measured at Vcc=3.6V, Temp=25C
Sampled over 1 minute

| Mode | Before | After |
| - | -: |  -: |
| Ready to Launch | 7.86uA | 4.64uA |
| Run  | 6.57uA | 6.00uA |

This about as low as we can go with optimization. Right now changing the font so a six does not have the top segment lit would save more power than removing *all* of the update code. That's right folks, the code that now runs on a TSL in Time Since Launch mode now uses less essentially an unmeasurable amount of power.   

### Even better

If I was cool, I would have used [graph coloring](https://en.wikipedia.org/wiki/Register_allocation#Graph-coloring_allocation) to optimally allocate these registers rather than static allocation. Unfortunately I am lazy and this would be much more work for probably an unnoticeable increase in battery life. Still, if you are reading this then you should probably implement this and send me a pull request with your awesome code! :)  

While you are at it, we could also optimize the order of assignments in each step to maximize the number of times that a register loaded in one step can be reused in the next step. I'm sure there is a general solution to this, but a brute force approach could just try all 4*4 orders and keep track of the one that has the lowest number of loads and use that one.

Keep in mind that these further optimizations will have diminishing returns beyond the extraordinary ones already in place. You will be lucky to find more than an additional 1 second of battery life over a 100 year run-time, so just know that you are doing it for the love of the cycles!

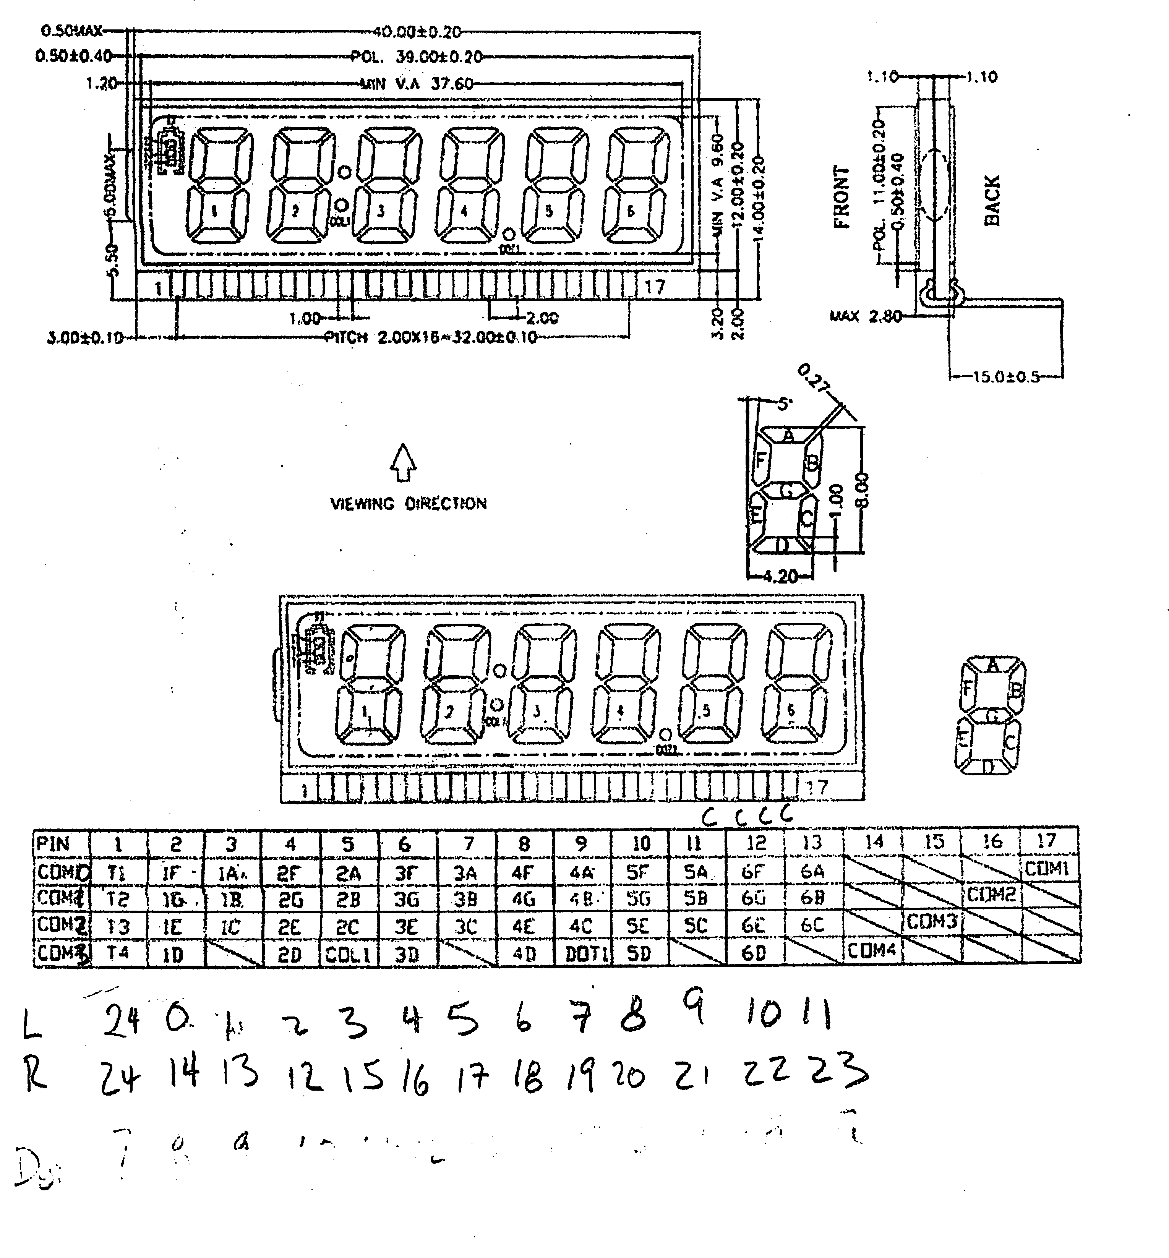
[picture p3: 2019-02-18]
TSL LCD pinout.png

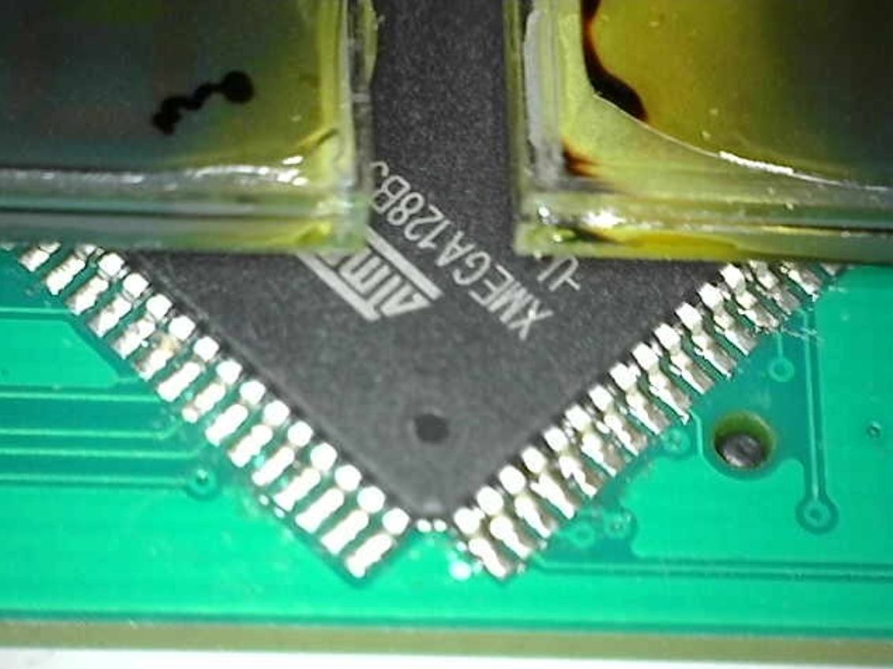
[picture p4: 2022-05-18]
hardware/orientation photos/orientation U1.png

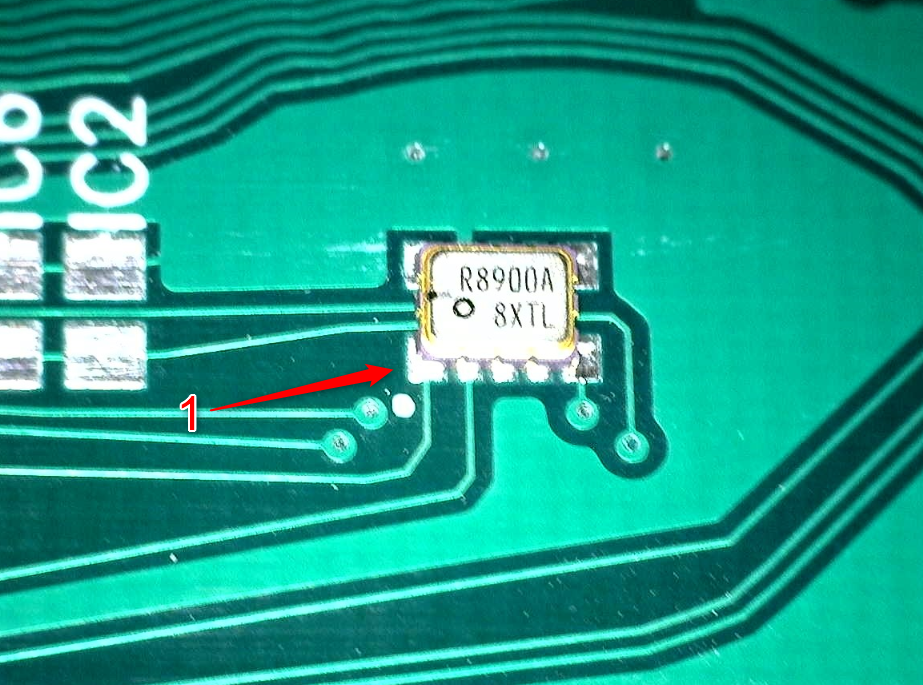
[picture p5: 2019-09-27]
hardware/orientation photos/orientation U3.png

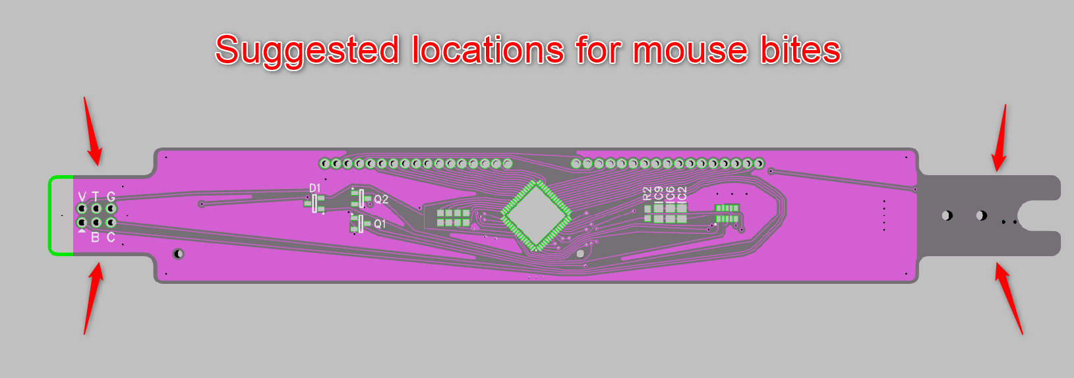
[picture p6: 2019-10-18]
hardware/mousebites.png

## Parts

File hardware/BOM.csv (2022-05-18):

RefDes | Name | Value | Manufacturer | Place | Subsitution | Budget Price at 1K units | URL
C1 | CAP_0603 | CAP CER 0.1UF 16V X7R 0603 | Murata |  | Possible | 0.013 | https://www.digikey.com/product-detail/en/murata-electronics-north-america/GCM188R71C104KA37D/490-4774-1-ND/1641693
C2 | CAP_0805 | CAP CER 47UF 6.3V X5R 0805 | Murata |  | Possible | 0.21 | https://www.digikey.com/product-detail/en/murata-electronics/GRM219R60J476ME44D/490-13249-1-ND/5877457
C3 | CAP_0603 | CAP CER 0.1UF 16V X7R 0603 | Murata |  | Possible | 0.013 | https://www.digikey.com/product-detail/en/murata-electronics-north-america/GCM188R71C104KA37D/490-4774-1-ND/1641693
C4 | CAP_0603 | CAP CER 0.1UF 16V X7R 0603 | Murata |  | Possible | 0.013 | https://www.digikey.com/product-detail/en/murata-electronics-north-america/GCM188R71C104KA37D/490-4774-1-ND/1641693
C5 | CAP_0603 | CAP CER 0.1UF 16V X7R 0603 | Murata |  | Possible | 0.013 | https://www.digikey.com/product-detail/en/murata-electronics-north-america/GCM188R71C104KA37D/490-4774-1-ND/1641693
C6 | CAP_0805 | CAP CER 47UF 6.3V X5R 0805 | Murata |  | Possible | 0.21 | https://www.digikey.com/product-detail/en/murata-electronics/GRM219R60J476ME44D/490-13249-1-ND/5877457
C9 | CAP_0805 | CAP CER 47UF 6.3V X5R 0805 | Murata |  | Possible | 0.21 | https://www.digikey.com/product-detail/en/murata-electronics/GRM219R60J476ME44D/490-13249-1-ND/5877457
J1 | LCD-7SEG-6DIG | GDC0570 17PIN TN Positive 6 Digit 7 Segment |  | DNP |  | 1.2 | https://www.aliexpress.com/item/GDC0570-LCD-Display-Module-Clock-6-Bit-8-Characters-Dynamic-Driving-TN-Type-LCD-Screen-Display/32753320423.html
J2 | LCD-7SEG-6DIG | GDC0570 17PIN TN Positive 6 Digit 7 Segment |  | DNP |  | 1.2 | https://www.aliexpress.com/item/GDC0570-LCD-Display-Module-Clock-6-Bit-8-Characters-Dynamic-Driving-TN-Type-LCD-Screen-Display/32753320423.html
J3 | PDI-6 |  |  | DNP
L1 | SM5730UWDN05 | SM5730 | Bivar |  | Possible | 0.0711 | https://www.digikey.com/product-detail/en/bivar-inc/SM5730UWDN05/492-2162-6-ND/6007622
L2 | SM5730UWDN05 | SM5730 | Bivar |  | Possible | 0.0711 | https://www.digikey.com/product-detail/en/bivar-inc/SM5730UWDN05/492-2162-6-ND/6007622
Q1 | 2N7002K |  | NXP-Philips |  | Possible | 0.05
Q2 | 2N7002K |  | NXP-Philips |  | Possible | 0.05
R2 | RES_0603 | 100OHM 5% |  |  | Yes | 0.016 | https://www.digikey.com/product-detail/en/susumu/RR0816P-101-D/RR08P100DDKR-ND/579969
S1 | ESE18R61D | ESE18R61D | Panasonic |  |  | 0.63 | https://www.digikey.com/product-detail/en/panasonic-electronic-components/ESE-18R61D/P13373SCT-ND/822309
U1 | MCU | ATXMEGA128B3-AU | Atmel |  |  | 2.045 | https://www.digikey.com/en/products/detail/microchip-technology/ATXMEGA128A3-AU/1886256
U3 | RTC | RX8804CE:XA3 | Epson |  |  | 3.37 | https://www.digikey.com/product-detail/en/epson/RX8804CE:XA3/SER4419CT-ND/10239842
U4 | Battery Holder | KEYSTONE1024 | Keystone |  |  | 1.601 | https://www.digikey.com/product-detail/en/keystone-electronics/1024/36-1024-ND/2178268
U5 | Battery Holder | KEYSTONE1024 | KeyStone |  |  | 1.601 | https://www.digikey.com/product-detail/en/keystone-electronics/1024/36-1024-ND/2178268
D1 | BAT54A |  | ON Semi |  | Possible | 0.03 | https://www.digikey.com/product-detail/en/BAT54ALT1G/BAT54ALT1GOSCT-ND/917808

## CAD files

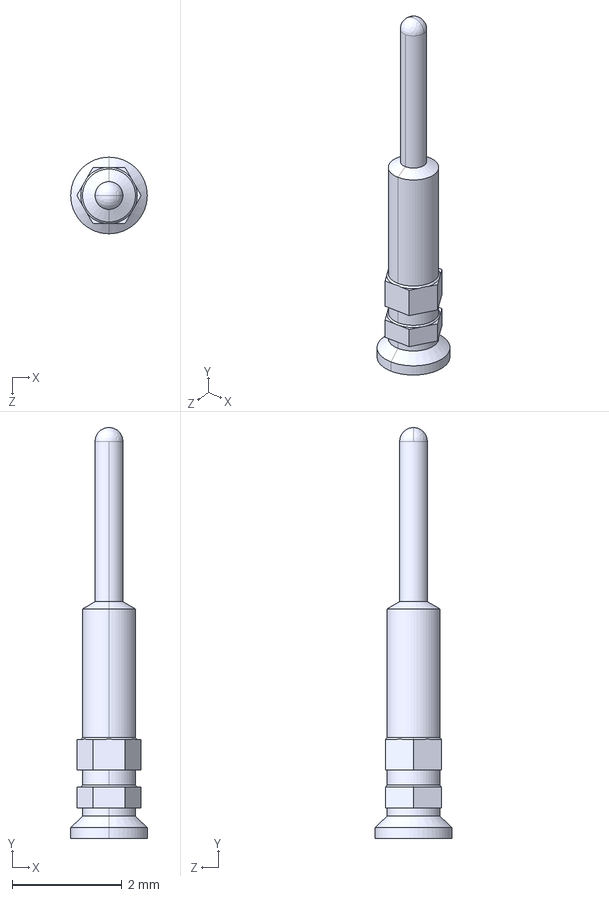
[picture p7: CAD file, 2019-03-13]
hardware/diptrace/3d/keystone-PN1997-2.STEP
1.40 x 7.49 x 1.40 mm

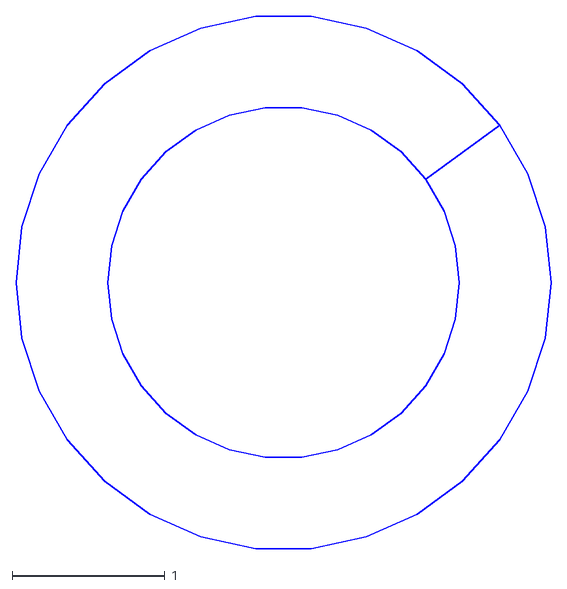
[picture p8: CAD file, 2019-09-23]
hardware/diptrace/mounting hole anulus shape phase2.dxf
3.50 x 3.48

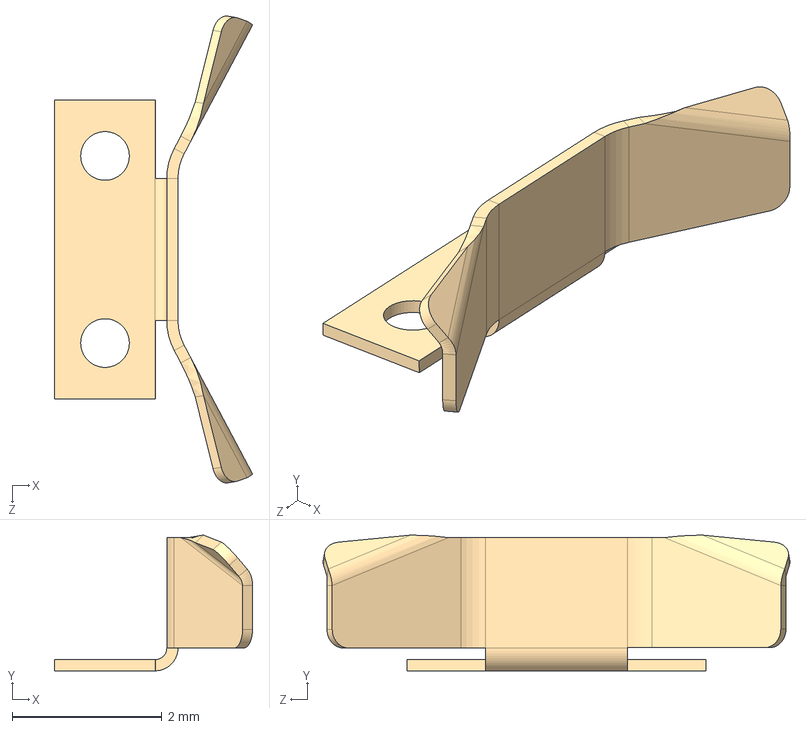
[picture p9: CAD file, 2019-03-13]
hardware/diptrace/3d/keystone-PN120.STEP
2.65 x 1.81 x 6.24 mm

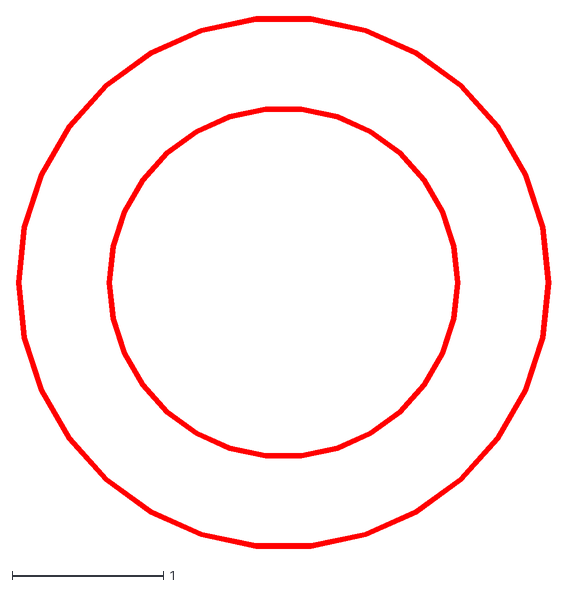
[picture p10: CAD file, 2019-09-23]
hardware/diptrace/mounting hole anulus shape phase1.dxf
3.53 x 3.51

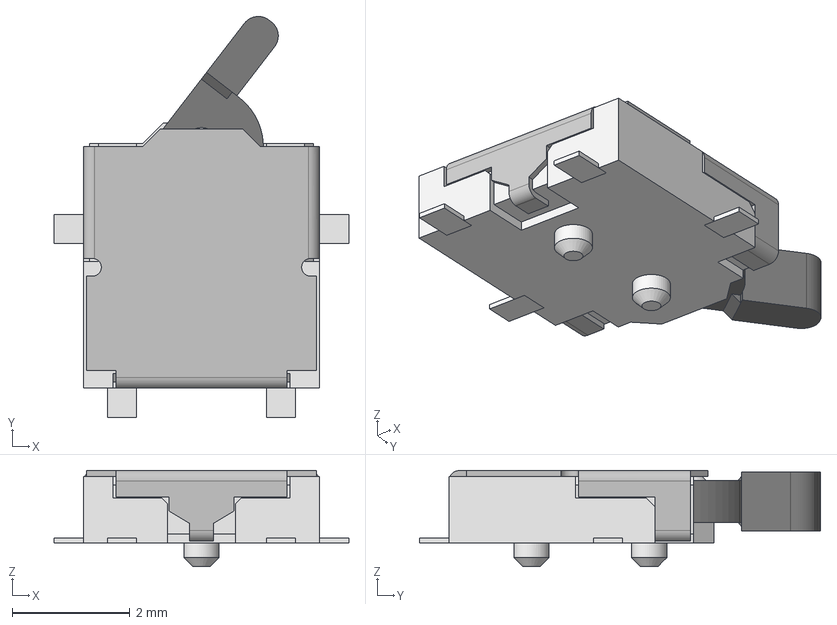
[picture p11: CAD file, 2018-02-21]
hardware/diptrace/3d/ESE18R61D-os.step
5.00 x 6.81 x 1.63 mm
sw-131-e18lv3-sk-1
sw-131-e18fm4-sk-1
sw-131-e18ts-f-sk-1 x 4
sw-131-e18cs-boss-pc-1

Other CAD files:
hardware/diptrace/3d/ESE18L61D.step
hardware/diptrace/3d/ESE18R61D.step
hardware/diptrace/3d/ESE18L61D.stp

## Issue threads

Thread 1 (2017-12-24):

Battery clip footprints wrong

bigjosh, 2017-12-24:
The holes from the drawings are too small.

Cure:
Interestingly, TPR just had the exact problem. Copy their footprints.

Closed 2018-04-11.

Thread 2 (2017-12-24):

Switch has the opposite action from what we'd optimally want

bigjosh, 2017-12-24:
The switch is normally closed when the arm is down - which would be how it sits when waiting to be triggered.

This will pull a small current though the switch, draining the batteries.

Cures:
1.  Find a switch that is normally open and closes when triggered. We'd still need a pull-up, but we could deactivate that pull-up the instant we trigger so no wasted power.
2. Use a huge external pull-up. With a 1M ohm we'd be only wasting 1uA, but that's an extra part and hate to waste anything. There is also a chance maybe stray static field would be enough to trigger? We'd need to maybe do some software filtering?
3. Poll the switch and only turn on the pull-up like once a second to check. This lowers the responsiveness when triggered and still wastes some power.

Closed 2018-03-09.

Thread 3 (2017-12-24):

Farthermost left and right digits are dimmer.

bigjosh, 2017-12-24:
Likely because the longer traces.

Cures:
1. Balance and shorten the trace lengths, but they are pretty close to shortest-path now.
2. Bump up the LCD duty cycle. Uses more power.

Closed 2018-02-25.

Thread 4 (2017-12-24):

No reverse battery protection

bigjosh, 2017-12-24:
This is by design since any electrical protection would use some power.

Cure:
Harsh warnings on the PCB about being super careful when inserting batteries.

Closed 2018-04-12.

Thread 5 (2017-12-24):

Traces under battery connectors

bigjosh, 2017-12-24:
With these tiny currents even just the capacitance of the metal battery connector running over the the LCD drive traces has an impact!

Just adding a TINY ~0.1mm gap between the battery clip and the PCB noticeably increased contrast on the segments whose traces run underneath. WOW!

Closed 2018-02-25.

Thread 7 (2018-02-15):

Battery clip holes still too small

bigjosh, 2018-02-15:
Should be 1.75mm - 2mm

Closed 2018-04-11.

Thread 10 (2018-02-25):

Possible interference between LCD pins and battery connector

bigjosh, 2018-02-25:

Closed 2018-03-09.

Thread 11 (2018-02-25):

Make battery connectors maybe 0.5mm tighter

bigjosh, 2018-02-25:
A little bend and they don't make good contact

Closed 2018-04-11.

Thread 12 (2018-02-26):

Test if 32K xtal is lower power than the internal ULP RC oscillator

bigjosh, 2018-02-26:

bigjosh, 2018-02-26:
docs imply 0.4uA savings? And much more accuracy so we could check in with the DS3231 that much less frequently .

bigjosh, 2018-07-13:
It does save about 0.3uA , but gonig with the ULP despite power costs for fewer parts and point of failure.

Closed 2018-07-13.

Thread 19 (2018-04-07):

Undersize mounting screw holes

bigjosh, 2018-04-07:
...so they just hold the screws. This way you can preload the screws before sliding the board in to make assembly easier.

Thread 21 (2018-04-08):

Try to put a keep out on the bottom side of the board where the mounting screws are?

bigjosh, 2018-04-08:
Concerned it might short through the mask against the aluminum cap?

bigjosh, 2018-04-12:
Routed traces to the breakaway around the screws.

Closed 2018-04-12.

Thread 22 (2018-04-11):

Potential short where board is screwed down to cap?

bigjosh, 2018-04-11:
Will the resist be good enough here?

Maybe we need to mill out a channel for the traces? Or maybe some kapton tape?

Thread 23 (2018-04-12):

Vias and traces under the ATMEGA

bigjosh, 2018-04-12:
Should be rerouted, this could short against the center pad of the chip if the mask rubs away over time.

bigjosh, 2018-05-03:
Closed 76044fd374a8802035ae153ff0e9514b01fce890

Closed 2018-05-03.

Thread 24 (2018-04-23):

Can we update the label on the PCB?

bigjosh, 2018-04-23:
new code is
CWT_BSE5DF4_1501

bigjosh, 2018-04-25:
CWT_BSE5DF4_1501_V3 ⚫️ (with space between V3 and the dot? (svg attached)

bigjosh, 2018-05-03:
Closed 76044fd374a8802035ae153ff0e9514b01fce890

Closed 2018-05-03.

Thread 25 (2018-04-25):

No traces on back side of PCB where they could short against end cap

bigjosh, 2018-04-25:

bigjosh, 2018-05-03:
Added keeepout

Closed 2018-05-03.

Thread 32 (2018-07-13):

Battery holder alignment holes too big

bigjosh, 2018-07-13:

Closed 2018-07-16.

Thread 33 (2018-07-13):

RX8900 footprint too small

bigjosh, 2018-07-13:

bigjosh, 2018-07-13:
Too narrow. Check against datasheet.

Closed 2018-07-16.

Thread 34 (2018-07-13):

Use smaller RX8900 variant?

bigjosh, 2018-07-13:
Would let the LCD sit closer to the PCB, but I like the bigger part because seams more physically robust and higher thermal mass.

bigjosh, 2018-07-16:
CW&T happy with current LCD-to-board clearance, so bigger chip stays.

Closed 2018-07-16.

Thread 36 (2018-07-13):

What actual 8 seg messages should we show on time lost and low batt?

bigjosh, 2018-07-13:

bigjosh, 2018-07-21:
How would you write LOW BATT in the 6x7 seg LCDs? The W and It's are hard I think!

cheewee2000, 2018-07-22:
if we have a pin we can connect to another segment, i think the display should go from a the full clock with the little battery icon turned on at 2.7V, then at 2.5V turn off the clock and only show the battery icon.

Writing out Low Batt in 7 seg would probably look like....
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
which doesn't look great.

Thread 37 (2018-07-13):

Add low battery detection

bigjosh, 2018-07-13:
Maybe use internal ADC? Trigger at 2.5V so plenty of time before we loose temp compensation at 2.4V?

bigjosh, 2018-07-13:
Once per day more than good enough. Maybe even once per week.

Closed 2018-12-26.

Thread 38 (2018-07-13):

Can we save some cycles by skipping ISR on FOUT interrupts?

bigjosh, 2018-07-13:
Maybe by messing with the interrupt priority bits to trick the PMIC into thinking an interrupt is already in progress?

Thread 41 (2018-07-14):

Should we show anything on the display on a warm start?

bigjosh, 2018-07-14:
Or just pick up where we left off?

bigjosh, 2018-07-14:
Silent restart is nice for like when the battery gets momentarily disconnected... but maybe we do want feedback for that so we know it is happening? Or maybe that never happens with new low power code since it can coast for several seconds without battery power.

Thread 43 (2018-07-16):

Try to make more room on the PCB for the level getting bent under the trigger switch

bigjosh, 2018-07-16:

bigjosh, 2018-07-16:
Tried moving switch in commit c764daa. We'll see if it helps.

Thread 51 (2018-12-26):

Skipped counts from rubbing

bigjosh, 2018-12-26:
DESCRIPTION:
The seconds counter (or Ready to Launch pattern) can skip a count when you rub the glass.

IMPACT:
While not catastrophic, this sucks because it skips are jarring to the user and would accumulate to make the Time Since Launch be fast in between battery changes unless we periodically correct it (which would cost power).

CURRENT BEST THEORY:
I think this is due to the fact that the signal from the RTC to the XMEGA that drives the 1Hz update tick (called `FOUT`) is (intentionally) very low power so it does not take much to glitch it, and apparently the static fields from rubbing the glass are enough. This is not completely unexpected.

MITIAGTION STRATEGY:
You would typically add a hardware RC filter or increase the drive on that signal, but these are both costly in terms of power.

I think I have a way to mitigate this while only increasing power a few percent by effectively adding a software low pass filter to the incoming FOUT signal on the XMEGA.

bigjosh, 2019-03-10:
Switched interrupt on FOUT to be on both edges and interlocked on both phases in ec39e9944f04327199e54861b12ef638854d7997

Closed 2019-03-10.

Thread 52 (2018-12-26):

"ClockError” failures after programming

bigjosh, 2018-12-26:
DESCRIPTION:
A programmed TSL will show “ClockError” some time after it has been programmed.

IMPACT:
This would be a sucky problem if the “clockerror” happened after the unit shipped, or (worse) after the trigger was pulled.

CURRENT BEST THEORY:
I think due to variance maybe the RTC backup capacitor is sometimes not getting fully charged before we program the start time and then reset the low voltage flag in the RTC. Int his case, since the voltage was still low when we reset the flag, it would just instantly get set again. We only check this flag when the XMEGA resets, so we do not notice until the next reset – which thanks to the problem below actually can happen spontaneously with some static. If this turns out to be the case, then the spontaneous reset issue was actually a lucky break because it helped uncover this issue!

MITIAGTION STRATEGY:
I just pushed a new firmware P0.7T that uses a 2-prong approach…

Firstly it uses a transistor that is built into the RTC to connect the backup capacitor to the battery for 1 second before resetting the low power flag. Hopefully this should make sure that the voltage on that cap is high enough that the RTC will not see a low voltage after we reset the flag.

Secondly, it causes a software reset immediately after setting the start time to the RTC. The idea here is that we will fail fast and at least catch any failure cases where the low voltage flag is still set by testing it during the programming sequence rather than whenever the next reset happens to occur.

bigjosh, 2019-03-10:
Resolved by letting the battery charge for a second before setting the time in 7a799e7b1bf7fc59ed855c384ab2b735c93e7ac9

Closed 2019-03-10.

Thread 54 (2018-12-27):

Use virtual ports on the FOUT pin to reduce power

bigjosh, 2018-12-27:
Since adding the filter/interlock in 50d4bf2053dc9b10c7b7abd4c559f003d6d92636, we now read the `FOUT` pin on each interrupt to check to make sure it really changed as a filter. We also now do this twice per second since we interrupt on both rising and falling edges so we can interlock on the changes.

We can reduce the cost of the this access by 50% by assigning that port to a virtual port. We do not currently use any of the virtual ports, so there is no cost to this optimization except writing the code.

bigjosh, 2019-03-10:
VPORT now on trigger pin, FOUT pin, and diganostics pins ports.

Closed 2019-03-10.

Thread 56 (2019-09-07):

Mounting hole too tight with new plating

bigjosh, 2019-09-07:

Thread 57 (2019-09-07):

Update firmware for new backup power circuit

bigjosh, 2019-09-07:
Now we need to leave the MOSFET inside the RX8900 closed so we don't get the voltage drop across it. We can depend on the new protection shotkey diode to prevent backflow into the MCU when batteries are removed.

Code can check the new bridged MCU pins to determine the PCB rev so firmware can be backwards compatible with old PCB tool.

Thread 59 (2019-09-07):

Copper between mounting hole and switch pad does not match gerbers

bigjosh, 2019-09-07:
Probably too tight in there. Maybe get rid of the bridge?  Maybe no ring on that mounting hole, just a pad that goes from the switch to under the screw?

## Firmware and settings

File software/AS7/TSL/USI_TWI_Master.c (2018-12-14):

/*****************************************************************************
*
* Atmel Corporation
*
* File              : USI_TWI_Master.c
* Compiler          : AVRGCC Toolchain version 3.4.2
* Revision          : $Revision: 992 $
* Date              : $Date: 2013-11-07 $
* Updated by        : $Author: Atmel $
*
* Support mail      : avr@atmel.com
*
* Supported devices : All device with USI module can be used.
*                     The example is written for the ATmega169, ATtiny26 and ATtiny2313
*
* AppNote           : AVR310 - Using the USI module as a TWI Master
*
* Description       : This is an implementation of an TWI master using
*                     the USI module as basis. The implementation assumes the AVR to
*                     be the only TWI master in the system and can therefore not be
*                     used in a multi-master system.
* Usage             : Initialize the USI module by calling the USI_TWI_Master_Initialise()
*                     function. Hence messages/data are transceived on the bus using
*                     the USI_TWI_Transceive() function. The transceive function
*                     returns a status byte, which can be used to evaluate the
*                     success of the transmission.
*
****************************************************************************/

#define	F_CPU	1000000UL	/* Hack until we fix things the right way (tm) */



#include <avr/io.h>
#include "USI_TWI_Master.h"
#include <util/delay.h>

#define BIT_TIME_US     (5)          // How long should should we wait between bit transitions?

// These are open collector signals, so never drive high - only drive low or pull high

// The init functions put the pins into " Totem-pole with Pull-up" mode
// In this mode the pin is:
//  pulled high when DIR =0
//  driven low when DIR =1

// Assumes OUT bits are still at startup default of 0

static inline void scl_pull_init(void) {
    PORTC.PIN1CTRL = PORT_OPC_PULLUP_gc;
}


static inline void sda_pull_init(void) {
    PORTC.PIN0CTRL = PORT_OPC_PULLUP_gc;
}

static inline void sda_drive_low(void) {
    PORTC.DIRSET = _BV( 0 );
}


static inline void sda_pull_high(void) {
    PORTC.DIRCLR = _BV( 0 );
}


// Float the pin and disconnect input buffer

static inline void sda_pull_disable(void) {
    PORTC.DIRCLR = _BV( 0 );
    PORTC.PIN0CTRL = PORT_OPC_TOTEM_gc | PORT_ISC_INPUT_DISABLE_gc;
    
}



static inline void scl_drive_low(void) {
    PORTC.DIRSET = _BV( 1 );
}

static inline void scl_pull_high(void) {
    PORTC.DIRCLR = _BV( 1 );
}

static inline uint8_t sda_read(void) {
    return PORTC.IN & _BV( 0 );
}

// Float the pin and disconnect input buffer

static inline void scl_pull_disable(void) {
    PORTC.DIRCLR = _BV( 1 );    
    PORTC.PIN1CTRL = PORT_OPC_TOTEM_gc | PORT_ISC_INPUT_DISABLE_gc; 
}





/*---------------------------------------------------------------
 USI TWI single master initialization function
---------------------------------------------------------------*/
void USI_TWI_Master_Initialise( void )
{

  sda_pull_init();
  scl_pull_init();

  /*
  while (1) {
    scl_drive_low();
    _delay_us(BIT_TIME_US);
    scl_pull_high();
    _delay_us(BIT_TIME_US);
  }
  */


  // This leaves us with both SCL and SDA high, which is an idle state
}


// Completely disconnect TWI pins and leave floating!

void USI_TWI_Master_disable( void )
{

    sda_pull_disable();
    scl_pull_disable();
    
}    


// Write a byte out to the slave and look for ACK bit
// Assumes SCL low, SDA doesn't matter

// Returns 0=success, SDA high (ACK bit released), SCL low.

static unsigned char USI_TWI_Write_Byte( unsigned char data ) {

    for( uint8_t bitMask=0b10000000; bitMask !=0; bitMask>>=1 ) {

        // setup data bit

        if ( data & bitMask) {
            sda_pull_high();
        } else {
            sda_drive_low();

        }

        // clock it out

        _delay_us(BIT_TIME_US);

        scl_pull_high();           // Clock in the next address bit

        _delay_us(BIT_TIME_US);

        scl_drive_low();

    }

    // The device acknowledges the address by driving SDIO
    // low after the next falling SCLK edge, for 1 cycle.

    sda_pull_high();            // Pull SDA high so we can see if the slave is driving low
    _delay_us(BIT_TIME_US);     // Not needed, but so we can see what is happening on the scope
    scl_pull_high();
    _delay_us(BIT_TIME_US);     // TODO: Don't need all these delays

    uint8_t ret = sda_read();   // slave should be driving low now
    scl_drive_low();            // Slave release
    _delay_us(BIT_TIME_US);

    // TODO: CHeck ret

    return(ret);

}

// readFlag=1 leaves in read mode
// readFlag=0 leaves in write mode
// Returns 0 on success, 1 if no ACK bit received.
// Assumes SCL high
// Returns with SCL low, SDA wahtever last bit (r/w bit) was

static unsigned char USI_TWI_Start( unsigned char slave , unsigned char readFlag) {

    // We assume that we enter in idle state since that is how all public functions leave us
    
    _delay_us(BIT_TIME_US);         // Make sure we have been in idle at least long enough to see the falling SDA

    // Data transfer is always initiated by a Bus Master device. A high to low transition on the SDA line, while
    // SCL is high, is defined to be a START condition or a repeated start condition.

    sda_drive_low();

    _delay_us(BIT_TIME_US);

    scl_drive_low();

    // A START condition is always followed by the (unique) 7-bit slave address (MSB first) and then w/r bit

    // The control word is latched internally on
    // rising SCLK edges and is eight bits in length, comprised
    // of a seven bit device address equal to 0010000b and a
    // read/write bit (write = 0 and read = 1).

    uint8_t controlword = (slave << 1) | readFlag;

    return USI_TWI_Write_Byte( controlword );

}

// Assumes on entry SCL low 
// Returns with bus idle, SCL high SDA high


static void USI_TWI_Stop(void) {

    // Data transfer ends with the STOP condition
    // (rising edge of SDIO while SCLK is high).

    // Q: Is this Really needed? Can we just do repeat starts and save this code? Spec is vague if address is reset on start.
    // A: Yes, we need this because it is possible that the FM_IC is holding the SDA line low
    // wait for us to clock out the MSB of the next byte!

    sda_drive_low();
    _delay_us(BIT_TIME_US);     // Give is a moment to stabilize in case
    scl_pull_high();
    _delay_us(BIT_TIME_US);

    sda_pull_high();            // SDA low to high while SCLK is high is a STOP
    _delay_us(BIT_TIME_US);

}

// Write the bytes pointed to by buffer
// addr is the chip bus address
// assumes bus is idle on entry, Exists with bus idle
// Returns 0 on success
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

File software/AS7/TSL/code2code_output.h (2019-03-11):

/*
 * code2code_output.h
 *
 * Created: 3/3/2019 12:37:11 AM
 *  Author: josh
 */ 


#ifndef CODE2CODE_OUTPUT_H_
#define CODE2CODE_OUTPUT_H_

// Note that these values are hardcoded in code2code so any changes 
// must be reflected there!

#define FOUT_VPORT (VPORT2)
#define FOUT_PIN   (2)

#define TRIGGER_VPORT (VPORT0)
#define TRIGGER_PIN (7)

// Count bottom 4 digits from 0000 to 5959 
// with a 1 second interlock on VPORT2.2
// FOUT must be low on entry or you will miss a second

extern void lcd_optimized_run_hour();
            
// Show the Ready Mode figure 8 pattern 
// with a 1 second interlock on VPORT2.2
// Run until 


extern void lcd_optimized_run_ready();

// Purrdee
// Just for show/fun. Takes about 0.5 sec

extern void lcd_optimized_run_sinewave();


#endif /* CODE2CODE_OUTPUT_H_ */

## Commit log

2017-11-27 10uA - Working all 12 digits blinking 8's @1Hz
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2018-01-14 Fully functional with fast count mode and fire pin.
    Pulls 15uA now. COuld at least 1/2 that by optimizing the LCD update steps.
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2018-02-02 With manual LCD trace layout - interferes with battery clips
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2018-02-02 Begin Autorounting
    Text is only on silk becuase to hard to make in copper.
    Need to try again with pin swap on.
    Need to add trip wire contacts.
    Maybe add pads for a blocking transistor, but has to be low leakage
2018-02-03 Battery clip holes to 1.3m, distance increase to ~50.3mm
    Clips were pressing too hard.
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2018-02-03 Good route with daiganal chip under battery. Batteries moved together and less tension.
2018-02-03 Really nice version with gold text and no silk except battery direction
2018-02-04 Oops, used left switch rather than right - fixed part name to match
    [ESE18L61D.step, ESE18L61D.stp, ESE18R61D.step]
2018-02-21 Add switch 3d model
    [ESE18R61D-os.step]
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2018-03-08 As shipped on rev2 prototype.
    Much more work to be done here.
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2018-04-11 Adjusted battery clip footprints
    Made hole bigger. oval shaped, closer together. Closes #11
2018-04-12 Added dual diode for reverse protection and VBAT holdup
    Closes #4
2018-04-12 Drop mounting holes from 1.93mm to 1.90mm
    Potentially to hold mounting screws in place while board is inserted. #19
2018-04-13 Rework breakaway traces to meet PCBWAY process requirements.
    0.25mm trace->edge
    0.35mm trace->hole
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2018-04-20 Move inside battery pins in 0.01 mils
    Clips still were a bit too tight
2018-04-20 Widen outer battery clip leads 0.05mm
    Also widens the distance between the leads, so hopefully less PCB flex.
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2018-05-11 Updated digit maps in code to match new PCB
    Chip swiched side, so all LCD pins flipped
2018-05-11 Trigger pin updated and new flash LEDs added to match new PCB
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2018-05-11 Cut LCD Refresh from 64Hz to 32Hz, seems to trim ~10uA from LCD power
2018-05-11 Switch to using test pin for fast forward, but no power savings.
2018-05-14 Now 2 flash LEDs in center, switch swapped to right hind version and more centered. NOT ROUTED
    Closeses #29, #28 and #27
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2018-06-06 Add missing connection from LEDs to BAT
2018-06-07 Updated to match new board. Runs, flashes. 4.5uA
    No RTC, inefficient LCD updates.
2018-06-30 TWI read and write working!!!!
    Had to fix polarity of the RESTART entrance. RESTART needed to read on this chip!
    [USI_TWI_Master.c]
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2018-07-16 Increased size of RX8900 footprint
    ...and moved lots of traces to accomodate. Closes #33
2018-07-16 Move vias away from battery holder edges. Shorten traces to MOSFETS.
2018-08-10 add working bom
    [BOM.csv]
2018-08-17 Update BOM for currently available parts
    [BOM.csv]
2018-08-17 Update C2
    [BOM.csv]
2018-08-26 L1 typo in BOM
    [BOM.csv]
2018-09-12 Add clearance around via and excise stub trace
    As requested by Worthington Assembly
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2018-12-14 Ok, finally got a comprehensive view of the FOUT after a RESET and SET
    This commit has all the instrumentation that got us there.
    [USI_TWI_Master.c]
2018-12-14 Remove instrumentatin. RC1
    Needs EEPROM file genrator and programming batch file.
    Needs more testing.
    Wants more power efficient seconds update and Ready for Launch pattern.
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2018-12-15 Low battery detection working
    Currently cuts at about 2.5-2.6V.
    FOR TESTING currently checks every 10 seconds on the 10 second mark.
    IN production this will be only once every 8 days.
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2018-12-16 Added diagnostics pin check every minute
    This lets use disable the RESET pin and still have it possible to do diagnostics.
    Becuase we are checking these pins inside the Time Since Lanuch loop, I put these pins onto a virtual port so we can check them very quickly.
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2018-12-23 Set all fuses in `programming\burnthis.bat`
    Intentionally set every fuse to a good vallue, just to be safe.
2018-12-23 Show reset reason, delay on clock set to charge capacitor, SW reset after clock set
    Also disables test pins for now.
2018-12-23 Catch bad interrupts and display an error message
    No effect. Wasn't bad interrupts. :/
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2018-12-27 Update programming batch file to account for extra charging delay when setting start time
2018-12-27 Add filter/interlock to Ready To Launch mode
    Filters out unwanted spuious interrupts from static that could to make the pattern skip a beat when the glass was rubbed.
    Note that even thought we are now doing twice as many interrupts (rising and falling edges of `FOUT`) and a lot more tests, the run power of this mode is still only ~5.5uA indicating that interrupt overhead uses negliable energy, which is a little unexpected.
2018-12-27 Update timer Since Lauch mode to use new filter/interlock to avoid skips from static noise
    Surprisingly even with twice as many interrupts, Time Since Lanuch mode is still only drawing ~6.1uA, further indicating that the only real software power wins left are in optimizting the segment update code.
2018-12-27 Update other modes to use new FOUT filter/interlock to avoid spurious steps
    Also update firmware version to 1.02
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2019-01-04 Drive trigger pin input low after pull to try to mitigate ESD resets
    THought this might help becuase when the switch is closed then resets are less likely, but does not seem to help.
2019-02-01 Add Space Mono font for the ledgend text along the bottom of the PCB
2019-02-01 Update schematic for RX8900 power source from XMEGA, caps on all XMEGA power pins,
2019-02-01 Update schematic to rotate trigger switch so ground is near mounting hole
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2019-02-11 Update BOM with digikey sourced flash LED
    [BOM.csv]
2019-02-11 Swap flash LEDs for digikey part
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2019-02-18 Fixed LCD map printing loops
2019-02-19 First working code generated by code!
    Counts 0-9. Massive power savings - down to 4.4uA at 2Hz!
    Still can optimize register loads and using idirect stores to squeeze that down a bit more.
    Need to make it real with 2 digits for minutes and seconds, and also need to add lead in code to get us to a round hour.
2019-02-21 New code-that-writes-code visual studio project.
    Working so far. Need to make the cut block from `lcd.c` to to the cpp file cleaner and better documented. Need to make the code that emmits the virtual port set up and loads the `r` registers on the 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
2019-03-03 Switched code2code from C to ASM output so we can use Y index
    The C compiler was complaining that you can't touch r27 from an `asm("")` statement.
2019-03-06 Fixed bug that made step 1031 and 1037 not clear some pixels
    NOTE TO SELF: You allways yell at other people for mixing data into a single variable and then you go and do it yourself so you deserve the consequences (1 hour wasted debugging the case when uint8_t -1 and 255 collided)!
2019-03-08 Whoowee! Trigger pin detection working on ready sequence.
    Folded in a new layer of abstraction where you can now specify a macro to run between steps, and that macro can Even execute a RET to end the step cycle. So cool!
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2019-03-10 Fix type in airtable insert
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2019-03-13 First pass at fixer daughterboard
    [keystone-PN120.STEP, keystone-PN1997-2.STEP]
2019-08-25 Revert schematic and PCB to last production version
2019-08-25 Replace LEDs with digikey part (layout incomplete)
2019-08-25 Get rid of XTAL
    We don't use it in the current configuration, so mind as well get rid of it and make the PCB cleaner.
2019-08-27 Increase coast time when changing batteries
    Added a double diode to keep the RTC caps from back feeding into the MCU. This also offers reverse battery inesertion protection.
    Connected FOE VBAT to prevent problems if this is floating when MCU is powered down.
    Added a resistor on the FOUT line to limit the current that backfeeds though the protect diode on the MCU GPIO pin when MCU is powered down.
    TODO: This means that the firmware will need to leave the RTC MOS open.
2019-08-27 Jumper PC5 to PC6 so the firmware can detect which PCB version this is
    We will need this to decide if we should open the MOS at startup.
2019-08-27 Flip switch terminals so ground lands next to the mountng screw.
2019-08-28 New layout complete. With Ground planes and contact points for the endcaps.
2019-08-28 Tweek ground plane edges so no notch around the title text. Tweek endcap pad mask.
2019-08-28 Add new footprint for XMEGA with no mask between pins
    As per PCBWAY
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2019-09-09 Increase no-silk on left endcap contact, increase groundplane and make 2-sided.
    Closes #58
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2019-09-09 Fix LED markings and pin assignments
2019-09-17 Update XMEGA pattern to reduce size of center pad to 7.3mm x 7.3mm
    As per DFM. Closes #55
2019-09-17 Increase mounting hole inside D by 0.1mm to 2.0mm
    Now these are plated though, the screws do not fit anymore. Hopefully this will be big enough. #56
2019-09-23 Make mounting holes not plated though, remove silk from trigger switch to accomidate
    [mounting hole anulus shape phase1.dxf, mounting hole anulus shape phase2.dxf]
2019-09-23 Decrease size of outtter mounting hole anulus
    [mounting hole anulus shape phase1.dxf, mounting hole anulus shape phase2.dxf]
2019-12-08 Update BOM.csv
    Update dual diode Digikey URL
    [BOM.csv]
2021-09-28 Update BOM and orientation photos for new U1 part
    [BOM.csv]
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2021-09-28 Update firmware for new pin assignments
    Should also be backwards compatible with the older board version pin assignments.
